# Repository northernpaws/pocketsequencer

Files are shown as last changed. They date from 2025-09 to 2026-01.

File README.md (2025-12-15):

# Pocket Sequencer

> This sequencer is being revised in revision 2 as a target for my embedded Rust audio processing framework, Rythm. Revision 2 will be a carrier board for one of the Rythm modules, and use the Rythm engine for the audio and sequencing.
>
> [https://github.com/northernpaws/rythm](https://github.com/northernpaws/rythm)

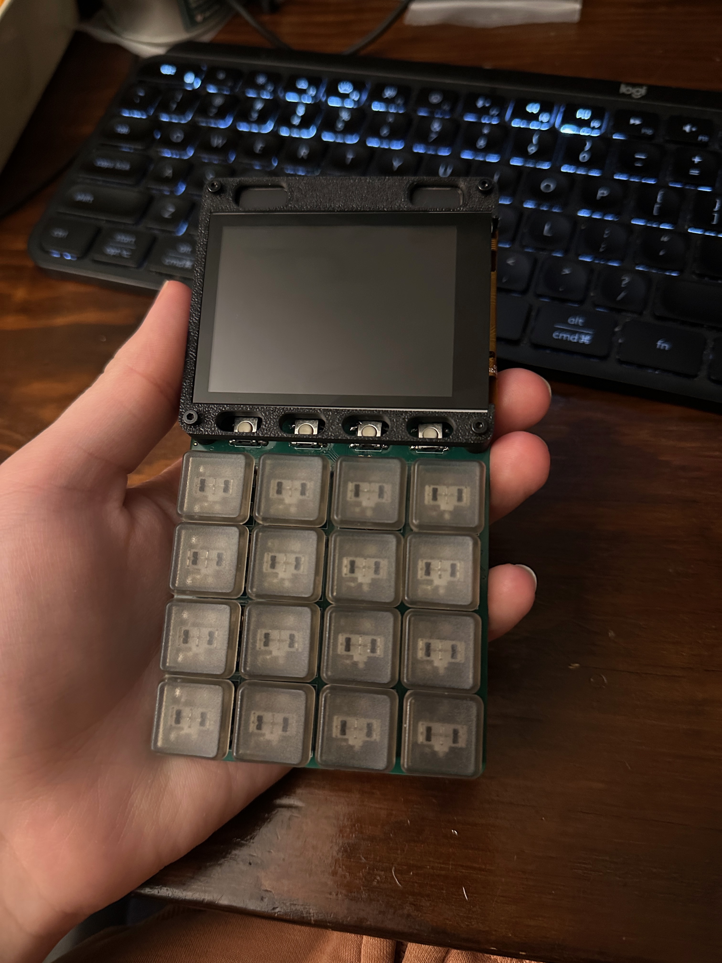
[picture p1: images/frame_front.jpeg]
Photo of front of board
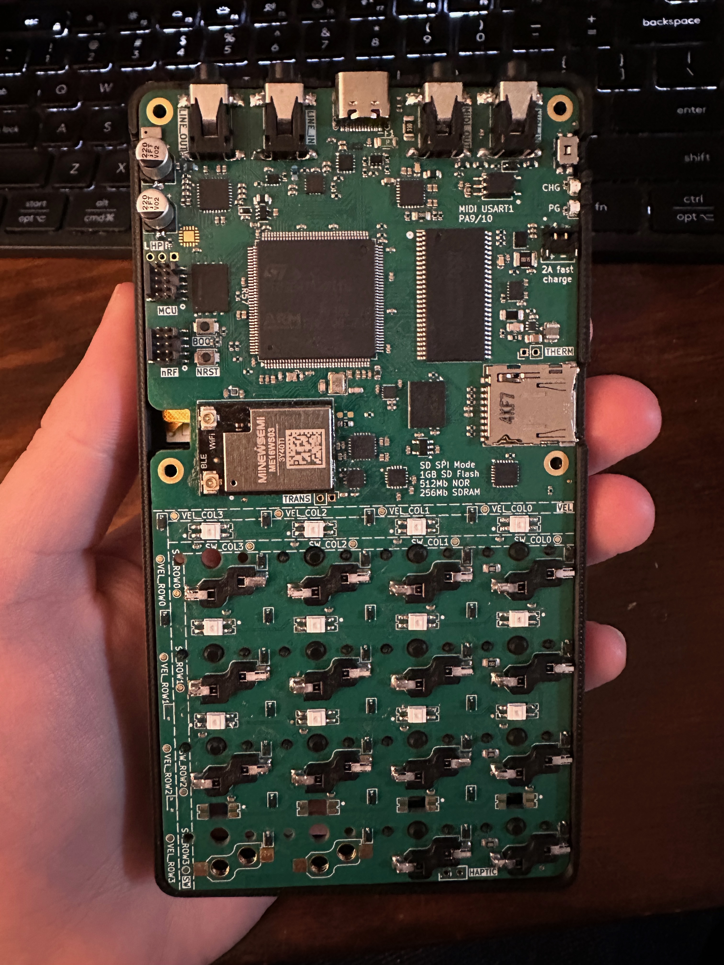
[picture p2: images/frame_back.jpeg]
Photo of back of board
|  |  |
|:---:|:---:|

[Board Schematic](https://kicanvas.org/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)

[Board v0.1 Errata](hardware/boards/v0.1/README.md)

This repository contains my project for an STM32H7-based sequencer, synthesizer, and sampler, all in a small phone-sized pocketable form factor. 

  * 480 MHz Arm® Cortex®-M7 32-bit Processor (`STM32H743ZIT6`)
    * Floating-point unit
    * DSP instructions
    * High-speed memory controller
    * Quad SPI interface for flash
    * High-speed USB host and device mode
    * Several SAI audio blocks
  * 2.8" 240x320 TFT IPS Display (`ER-TFT028A2-4`)
  * 24 bit Audio Codec (`NAU88C22YG`)
    * DAC: 94dB SNR
    * ADC: 90dB SNR
    * 1W 8Ω BTL speaker driver
    * 40mW 16Ω headphone driver
  * Optional Bluetooth and Wifi (`nRF5430`)
    * Wirelessly connect Bluethooth headphones and speakers
    * Supports various high-fedality audio protocols
    * BLE MIDI
    * Wifi sample management and transfer
  * Interal stereo 8W speakers speaker
  * Internal MEMs microphone
  * SDRAM for sample pool and audio processing
    * Part allocated to in-memory sample pool for project
    * Part allocated to audio effects processing
    * Variable sizes in similar footprint available, up to 512Mbit:
        * 16bit * 48000Hz = 768,000b/s = 0.768Mb/s
        * 128Mb / 0.768Mb/s = 166.66 seconds of mono audio (`IS42S16800J-7TL`)
        * 256Mb / 0.768Mb/s = 333.33 seconds of mono audio (`IS42S16160J-7TLI`)
        * 512Mb / 0.768Mb/s = 666.66 seconds of mono audio (`IS42S16320F-7TLI`)
  * Micro SD Card
    * Saving and loading projects
      * Transfer and back up projects to a computer
    * Saving and loading samples
      * Load samples from a computer
      * Save samples recorded on the device
  * 3.3v NOR Flash (`MT25QUxxxxxx1xW7` 256M/128M/64M)
    * Stores device settings
    * Small storage space for projects and samples without SD card
    * Provides storage for cross-SD card samples
  * USB-C
    * USB-PD fast charging
    * Possible future audio interface mode
    * USB MIDI in and out
  * MIDI in/out via TRS minijack type A
  * 16 Multi-Purpose primary keys
    * Hot-swappable Kalih V1 Choc keyswitches
    * Addressable RGB LEDs for state indicators
  * Accelerometer and Gyroscope (`LSM6DS3`)
    * Can be used as sequencer parameters
    * Can be recorded for automation inputs

Photo of front of board

## Step Sequencer

The step sequencer on the device is modeled after popular semantics used by hardware sequencers, such as the Elektron Digitone and Digitakt, OP-1, OP-Z, Pocket Operators, Woovebox, etc.

> The hard requirements of the step sequencer and audio engine are not defined yet because they are under active development.

  * As many projects as the SD card or internal memory can store
    * 128 Patterns (TBD)
      * 8-16 Audio or MIDI tracks per pattern (TBD)
    * 8-24 Songs (arrangements of patterns) (TBD)
  * 8-16 voice polyphony (TBD)
    * 2-3 LFO per voice (TBD)

## Audio Samples

The primary audio engine runs in 32-bit and supports stereo audio.

### Sampling

The sampling engine runs 16bit 44.1Khz and saves and loads samples in single-channel mono.

Samples recoded from the internal or external mic are sampled at 24 bits into the device's SDRAM to provide a decent noise floor, and then filtered and downsampled to 16 bits for saving after they've been edited by the user.

The 16bit @ 44.1Khz sampling parameters provdes a good balance between audio quality, and reasonable utilization of the SDRAM without needing extremely large and expensive SDRAM chips:

```
16bit * 48000Hz = 768,000b/s = 0.768Mb/s
128Mb / 0.768Mb/s = 166.66 seconds of mono audio
256Mb / 0.768Mb/s = 333.33 seconds of mono audio
512Mb / 0.768Mb/s = 666.66 seconds of mono audio
```

> Note that some of the space calculated above (actual amount will be configurable) is allocated to the audio effects processing chain, i.e. for reverb and delay. 

## References

### Debugging

 - HardFault: Under XPERIPHERALS in Cortex-debug check the `CFSR_UFSR_BFSR_MMFSR` register to see the fault code and reference: https://community.st.com/t5/stm32-mcus/how-to-debug-a-hardfault-on-an-arm-cortex-m-stm32/ta-p/672235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

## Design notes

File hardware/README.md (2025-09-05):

# Hardware

## Components

  * [480 MHz Arm® Cortex®-M7 32-bit Processor (`STM32H743ZIT6`)](https://www.st.com/en/microcontrollers-microprocessors/stm32h743zi.html)
    * Floating-point unit
    * DSP instructions
    * High-speed memory controller
    * Quad SPI interface for flash
    * High-speed USB host and device mode
    * Several SAI audio blocks
  * [24 bit Audio Codec (`NAU88C22YG`)](https://www.nuvoton.com/products/smart-home-audio/audio-converters/audio-codec-series/nau88c22yg/)
    * DAC: 94dB SNR and -84dB THD (“A” weighted)
    * ADC: 90dB SNR and -80dB THD (“A” weighted)
    * Integrated BTL speaker driver: 1W into 8Ω
    * Integrated head-phone driver: 40mW into 16Ω
  * [Optional Bluetooth Audio & MIDI (`nRF5340`)](https://www.nordicsemi.com/Products/nRF5340)
    * Wirelessly connect Bluethooth headphones and speakers
    * Connect devices for BLE MIDI inputs and outputs
    * uFL connector for case-mounted antenna
  * [Optional Wi-Fi (`ESP32-S2-MINI-2U`)](https://www.espressif.com/sites/default/files/documentation/esp32-s2-mini-2_esp32-s2-mini-2u_datasheet_en.pdf)
    * Wi-Fi sample management and transfer
    * uFL connector for case-mounted antenna

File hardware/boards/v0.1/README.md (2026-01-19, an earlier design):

# v0.1

## Components

  * [480 MHz Arm® Cortex®-M7 32-bit Processor (`STM32H743ZIT6`)](https://www.st.com/en/microcontrollers-microprocessors/stm32h743zi.html)
    * Floating-point unit
    * DSP instructions
    * High-speed memory controller
    * Quad SPI interface for flash
    * High-speed USB host and device mode
    * Several SAI audio blocks
  * [24 bit Audio Codec (`NAU88C22YG`)](https://www.nuvoton.com/products/smart-home-audio/audio-converters/audio-codec-series/nau88c22yg/)
    * DAC: 94dB SNR and -84dB THD (“A” weighted)
    * ADC: 90dB SNR and -80dB THD (“A” weighted)
    * Integrated BTL speaker driver: 1W into 8Ω
    * Integrated head-phone driver: 40mW into 16Ω
  * [Optional Bluetooth Audio & MIDI (`nRF5340`)](https://www.nordicsemi.com/Products/nRF5340)
    * Wirelessly connect Bluethooth headphones and speakers
    * Connect devices for BLE MIDI inputs and outputs
  * [Optional Wi-Fi (`nRF7002`)](https://www.nordicsemi.com/Products/nRF7002)
    * Wi-Fi sample management and transfer

## Observations

### Routing

  - In next revision, use larger STM32 package. Ran out of pins on the left side due to the FMC and SDRAM, and had to route several GPIO across the entire board, including some interrupt traces in the power layer. Ran out of ADC pins for the velocity pads and had to add an $8 IO expander.

## Errata

 - QUADSPI CS should be NSS capable pin for automatic hardware peripheral control. Use PG6 and swap USB_INT to PD6.
 - Micro SD Card detect pins weren't connected, card detection needs to happen in software.
 - SPI1 hardward CS pins should be PA4, PA15, or PG10. Currently using PA4 (SD CARD) and PC13 (internal flash).
 - Unused key matrix pins should be connected to VCC via a pull-up.
 - Keypad diodes should be pointing to the columns, not the rows.
   - "Once the TCA8418 has had the keypad array configured, it will enter idle mode when no keys are being pressed.
      All columns configured as part of the keypad array will be driven low and all rows configured as part of the
      keypad array will be set to inputs, with pull-up resistors enabled. During idle mode, the internal oscillator is turned
      off so that power consumption is low as the device awaits a key press."
  - Missing pull-up on keypad interrupt. Compensated for in software.
  - Fuel gauge interrupt missing pull-up resistor.
  - Mounting holes are not grounded, oops..
  - PG and cahrger lights are on regardless of power state
  - Should have a 3v3 power light
  - Somehow connect vref from the BMP port to the power button on confirmation
  - Should add flow control pins to RF UART "H:4 HCI transport protocol (requires HW flow control from the UART)".
  - Touch screen connector is inverted...
  - LED footprint needs longer pads with some overhang
  - Dispaly connector needs slightly longer pads
  - Display mode pins are backwards...
  - LEDs need a power enable switch tied to the main regulator, they never shut off.
  - Either attach power enable pin to the BMP's Vref so the BMP can assert it high, or have a flashing/development jumper on the back.
  - TCA8418 doesn't provide a way to query the matrix state after an active reset. The TAC8418 only emits keypress events when they happen, so we can't check on power on if a key is held from before a reset.
  - The filtering capacitors on the audio line in and out are too small, they should be at least 47uF. In their current 1uF value, they cut out large parts of the low-end.
  - The filter capacitors on the audio line in and out where acidentally changed from film to ceramics during BOM selections, causing extra signal noise.

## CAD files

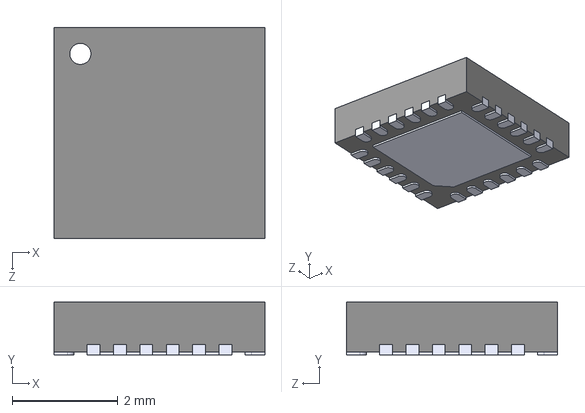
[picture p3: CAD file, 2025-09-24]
hardware/3dmodels/TAS2505IRGER.step
4.00 x 1.00 x 4.00 mm

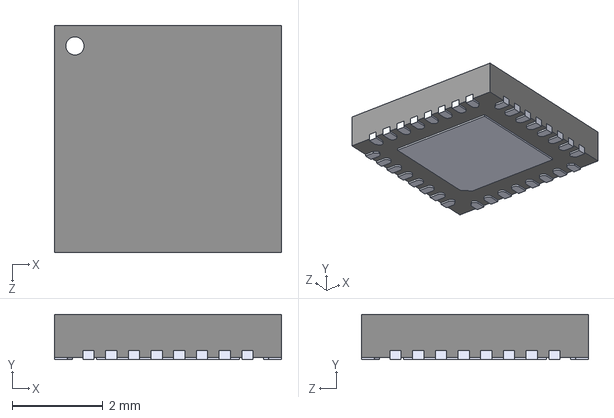
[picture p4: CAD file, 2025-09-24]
hardware/3dmodels/TLV320DAC3100IRHBT.step
5.00 x 1.00 x 5.00 mm

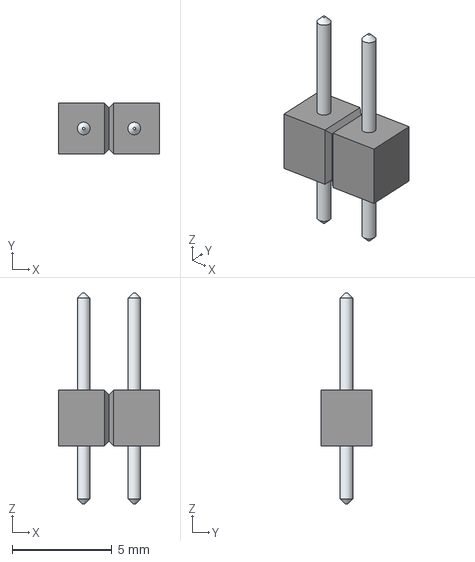
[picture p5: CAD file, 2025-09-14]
hardware/3dmodels/825-22-002-10-001101.stp
5.08 x 2.54 x 10.6 mm
LeadsArray

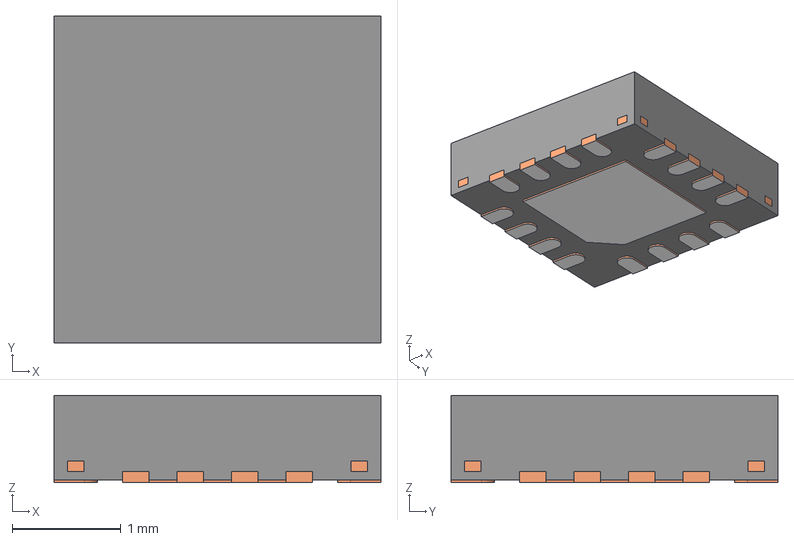
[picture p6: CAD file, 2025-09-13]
hardware/3dmodels/ADS7128IRTER.stp
3.00 x 3.00 x 0.8 mm
BODY-QFN
FRAME-RTE0016C
PIN1-ID

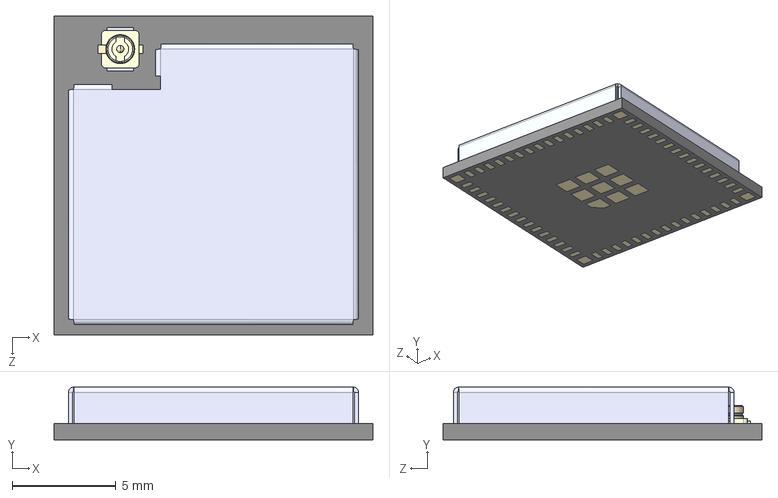
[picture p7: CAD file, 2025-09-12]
hardware/3dmodels/ESP32-S3-MINI-1U-N8.STEP
15.4 x 2.55 x 15.4 mm
ESP32-S3-MINI-1U-N8_ESP32-C3-MINI-1-N4
antenna jack

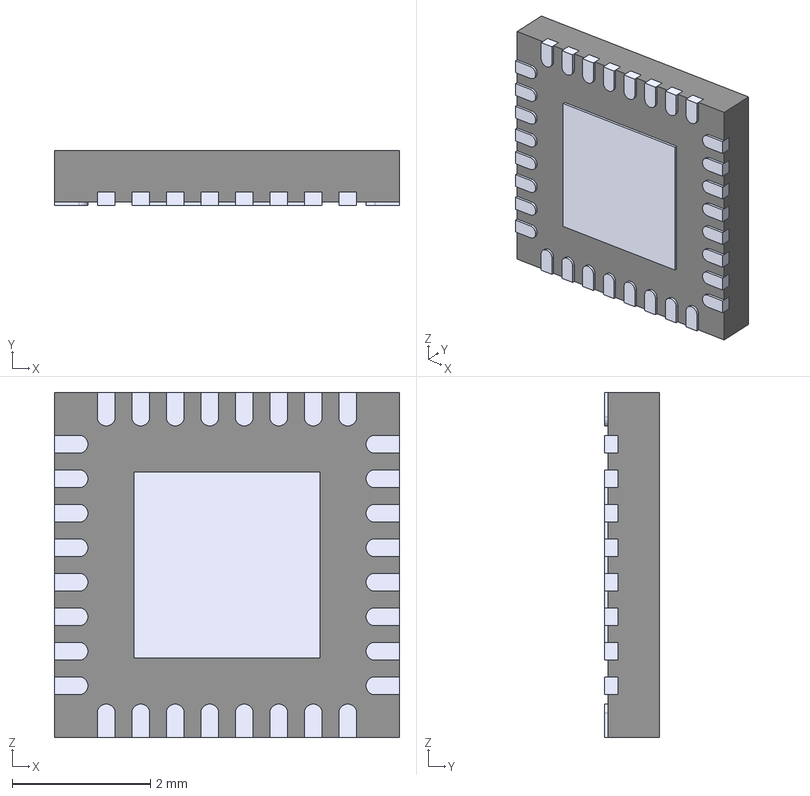
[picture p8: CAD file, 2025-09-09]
hardware/3dmodels/NAU88C22YG.STEP
5.00 x 0.8 x 5.00 mm
Body_Solid1
Body001_Solid1
Array_Solid1 x 8
Array001_Solid2 x 7
Body002_Solid1
Array002_Solid1 x 8
Array003_Solid2 x 7
Body003_Solid1
Body004_Solid1

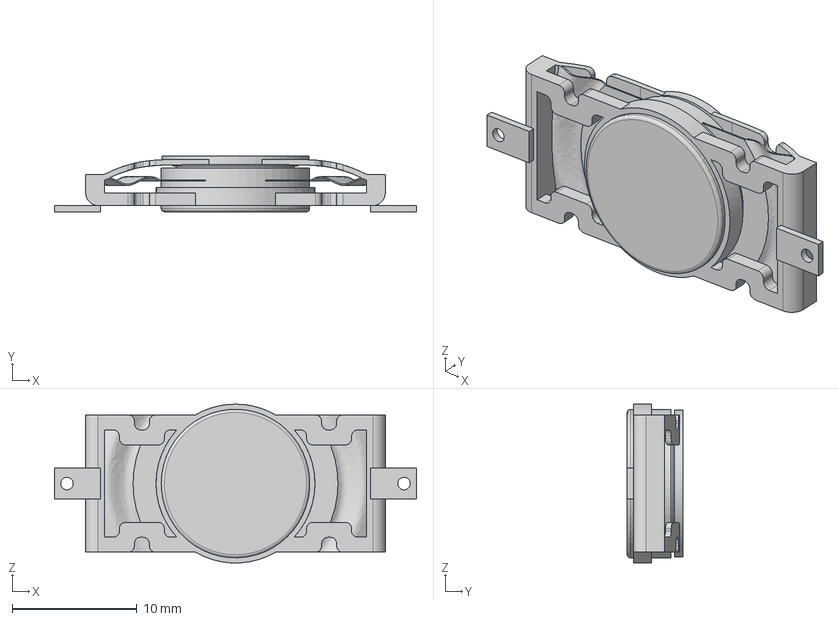
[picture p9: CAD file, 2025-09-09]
hardware/3dmodels/DAEX-9-4SM.step
29.0 x 4.45 x 12.7 mm

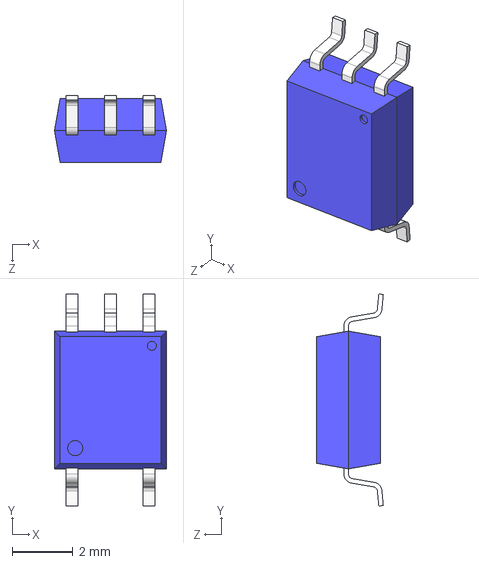
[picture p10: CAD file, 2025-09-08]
hardware/3dmodels/5pin SO6.step
3.70 x 7.00 x 2.20 mm

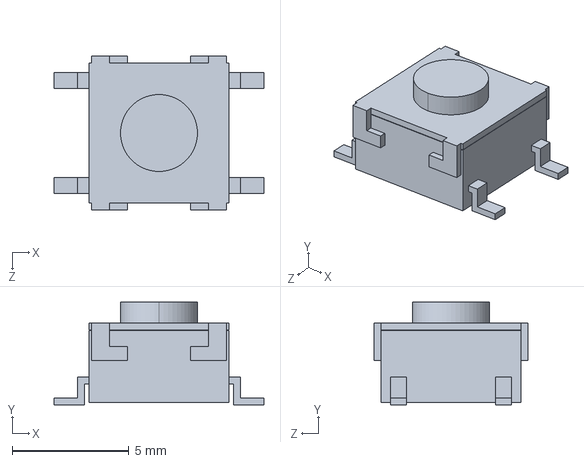
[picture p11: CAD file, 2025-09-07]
hardware/3dmodels/B3S_100[].step
9.00 x 4.40 x 6.60 mm

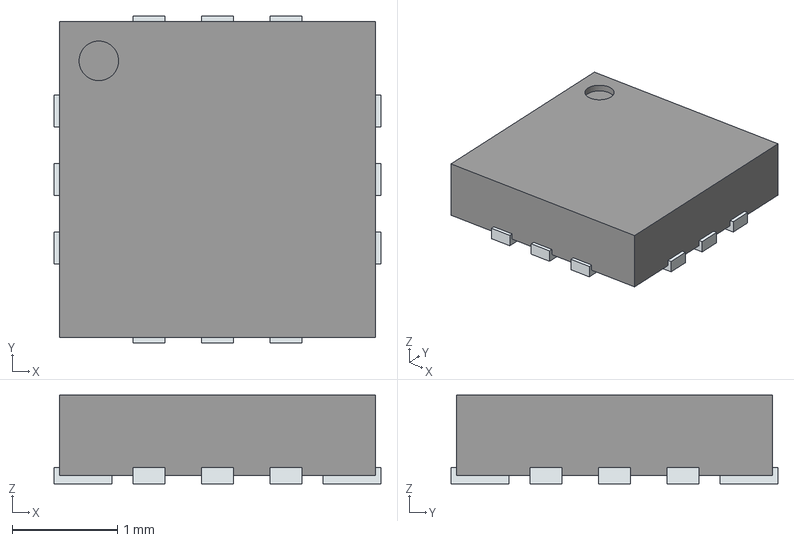
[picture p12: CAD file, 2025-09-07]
hardware/3dmodels/DA7280-00FVC.stp
3.10 x 3.10 x 0.84 mm
PinsArrayLR
PinsArrayTB

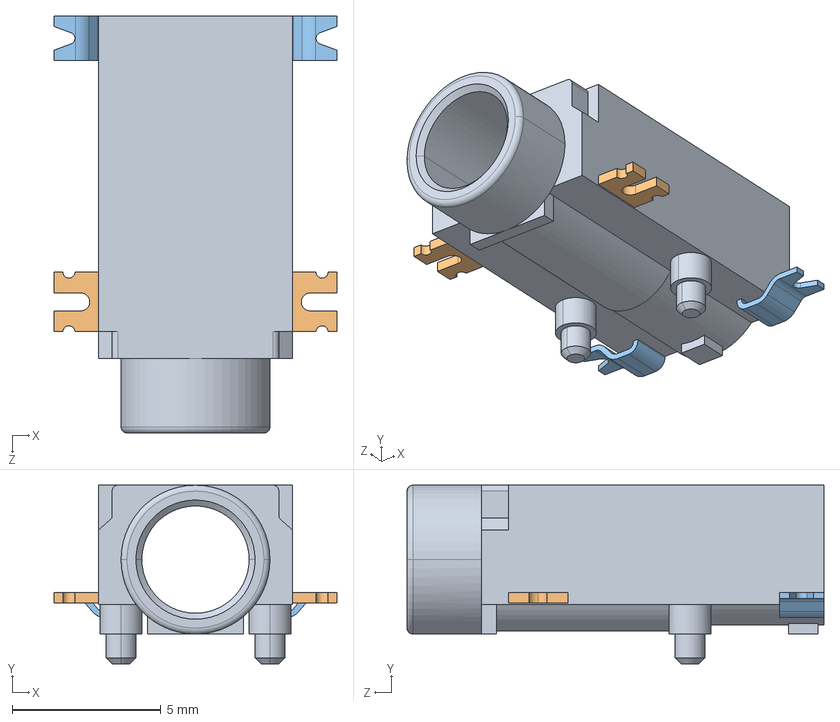
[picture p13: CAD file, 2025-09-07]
hardware/3dmodels/lumberg_1503_02.stp
9.50 x 6.00 x 14.0 mm

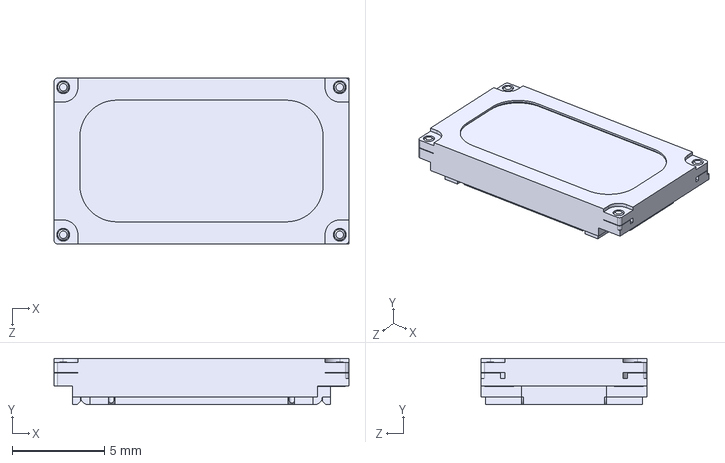
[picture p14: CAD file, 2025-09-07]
hardware/3dmodels/Same_Sky_CMS-160925-078SP.step
16.0 x 2.50 x 9.00 mm

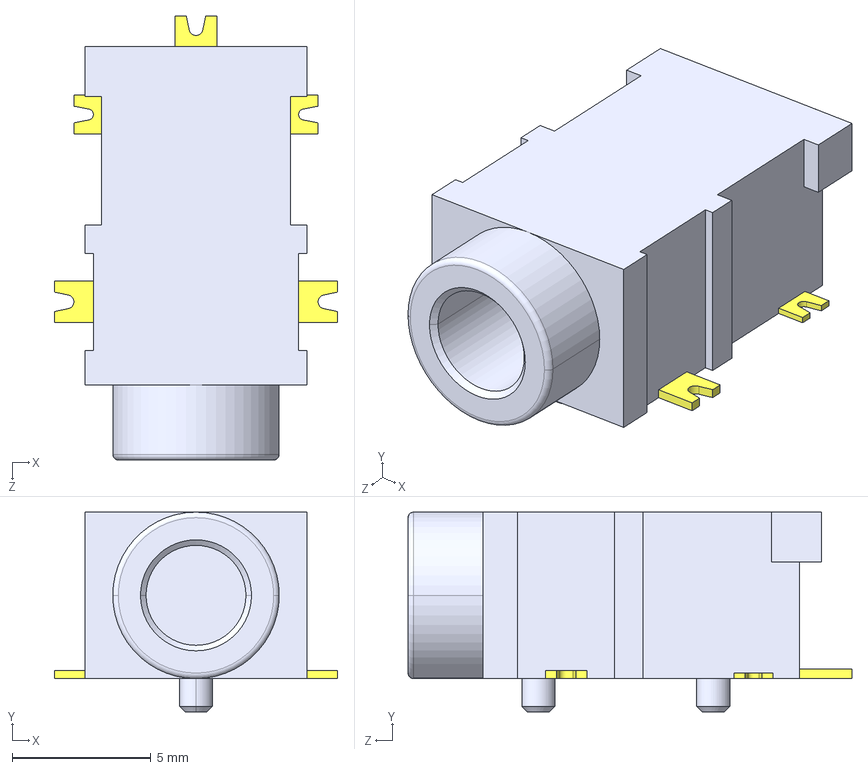
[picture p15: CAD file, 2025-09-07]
hardware/3dmodels/lumberg_1503_03.stp
10.2 x 7.20 x 16.0 mm

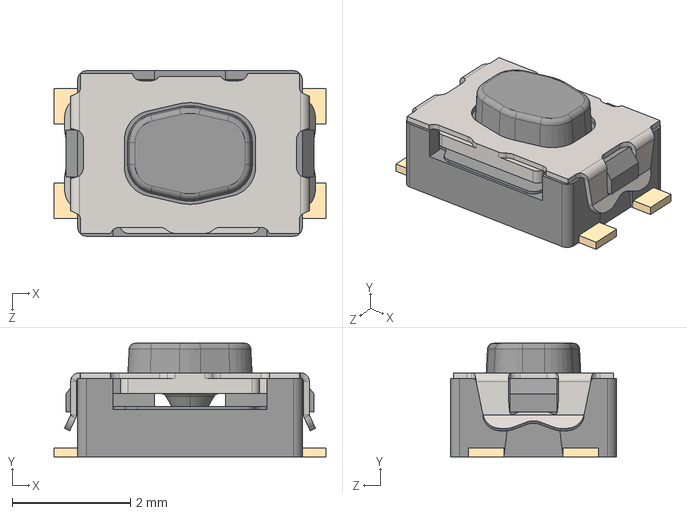
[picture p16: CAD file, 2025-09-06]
hardware/3dmodels/KMR221NG_LFS.stp
4.60 x 1.92 x 2.80 mm

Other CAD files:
hardware/3dmodels/WM8904CGEFL_RV.step
hardware/3dmodels/LED_SK6812MINI-E.step
hardware/3dmodels/NORA-B100.step
hardware/3dmodels/2082940020.stp
hardware/3dmodels/436331045822.stp
hardware/3dmodels/5034800540.stp
hardware/3dmodels/532610271.STEP
hardware/3dmodels/541325097.stp
hardware/3dmodels/687106182122+(rev1).stp
hardware/3dmodels/AS01808AO-SC18-WP-R.step
hardware/3dmodels/BQ27531YZFR-G1.step
hardware/3dmodels/CON10_2X5_DUK_FTSH_SAI.step
hardware/3dmodels/CON14_2X7_DUK_FTSH_SAI.step
hardware/3dmodels/DM3AT-SF-PEJM5.stp
hardware/3dmodels/DM3BT-DSF-PEJS.stp
hardware/3dmodels/ECS-.327-12.5-1210-TR.step
hardware/3dmodels/ER-TFT028-4.2.stp
hardware/3dmodels/ER-TFT028-4.2.x_t
hardware/3dmodels/FSA2466UMX.step
hardware/3dmodels/FTSH-105-01-F-D-K.step
hardware/3dmodels/FTSH-105-01-F-D-K.stp
hardware/3dmodels/FTSH-105-01-F-DV-K.stp
hardware/3dmodels/FTSH-107-01-F-DV-K.stp
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

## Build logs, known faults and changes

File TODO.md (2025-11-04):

# rev 2

 - QUADSPI CS should be NSS capable pin for automatic hardware peripheral control. Use PG6 and swap USB_INT to maybe PD6? 
 - Run LCD display DMA in circular mode, and use half-interrupt and end interrupt to queue double-buffer frame drawing in sync with DMA transfer speeds. 
   - "On the STM32, you can allocate one big array, and use the two halves as double buffer. There is a half-transfer interrupt (when enabled) which tells you that the first half is filled and ready for processing, and the second half is being modified. Then you'll get a transfer complete interrupt when the second half is ready and (in circular mode) it goes on updating the first half again. On higher-end controllers (STM32F4, STM32F7), there are actually two memory addresses for each DMA channel, the buffers halves do not need to be contiguous, and you can even change the address of the inactive buffer on the fly."

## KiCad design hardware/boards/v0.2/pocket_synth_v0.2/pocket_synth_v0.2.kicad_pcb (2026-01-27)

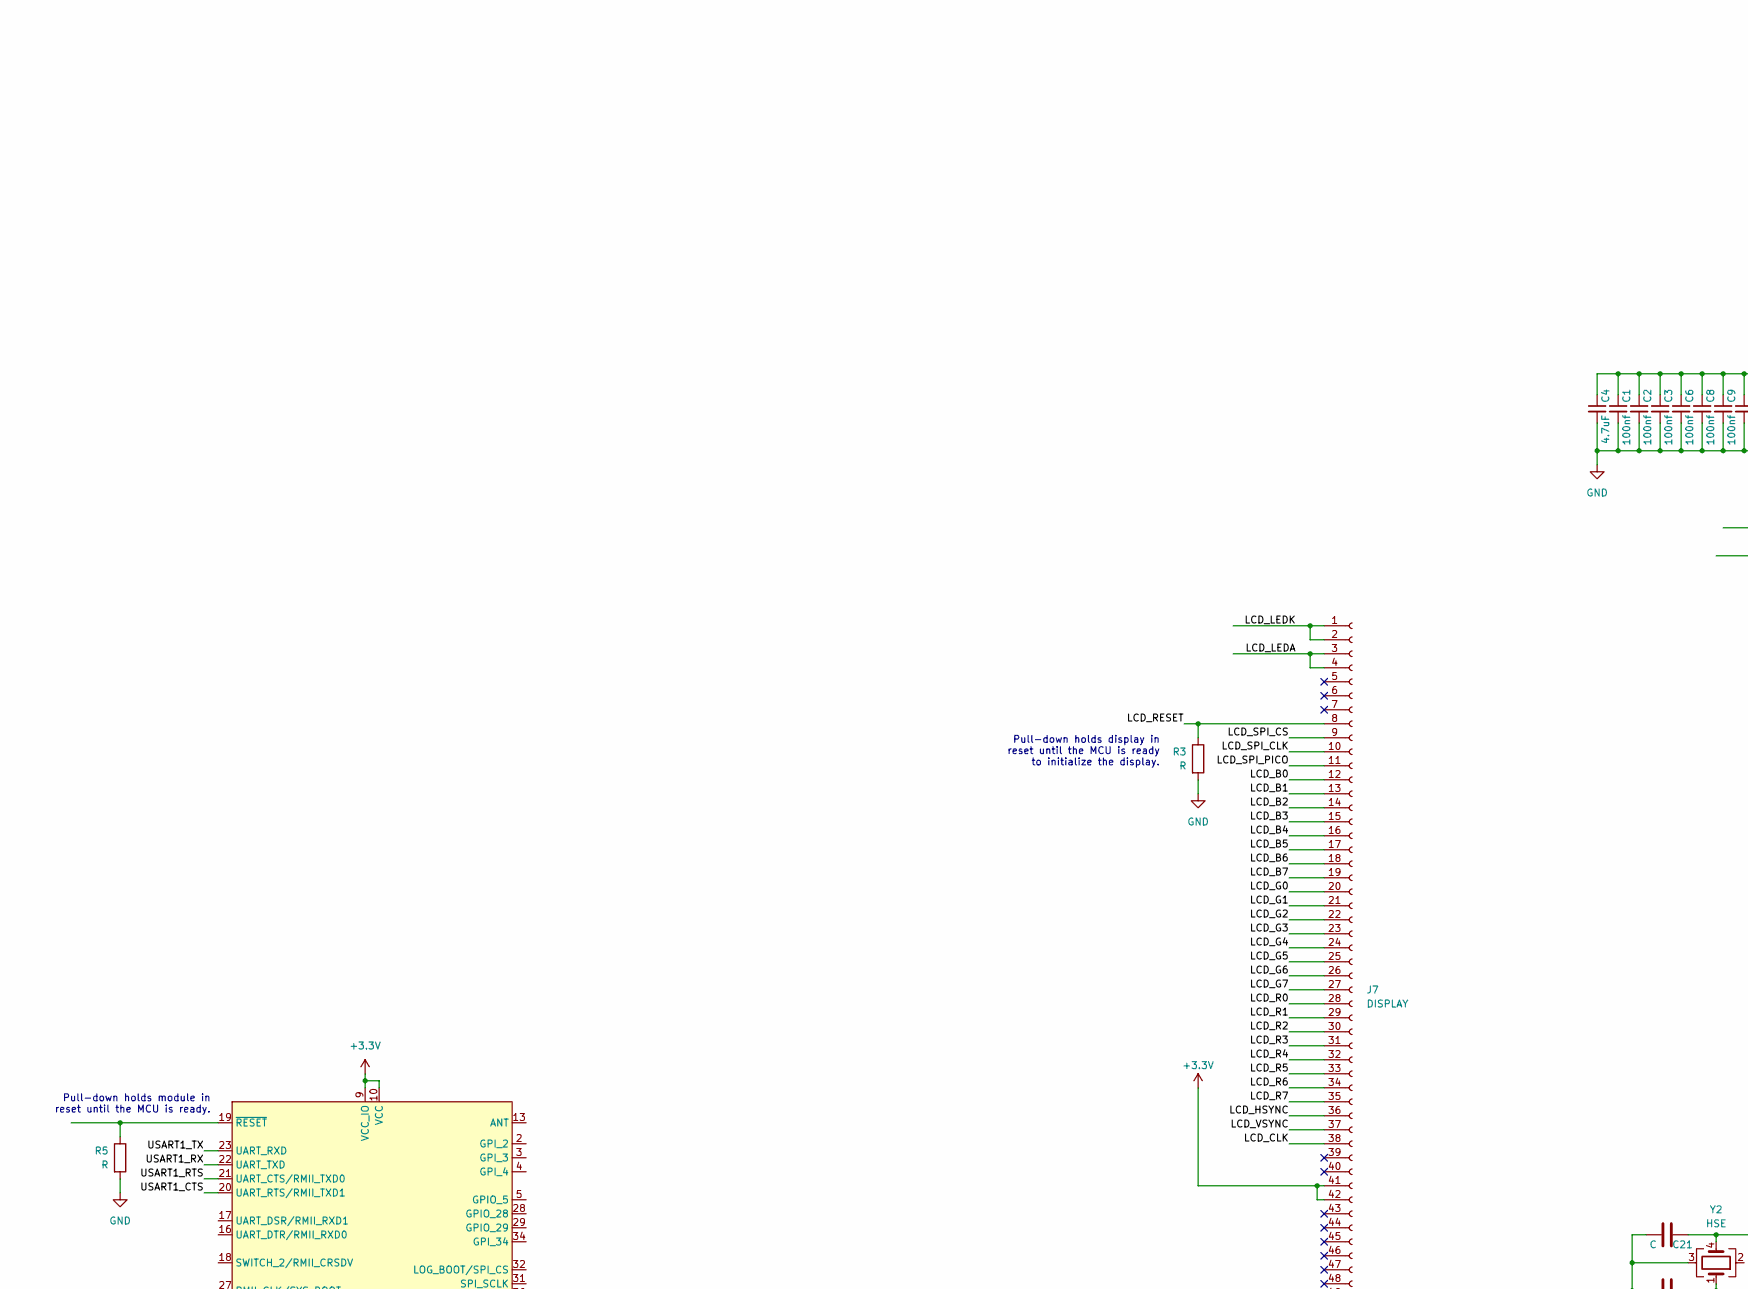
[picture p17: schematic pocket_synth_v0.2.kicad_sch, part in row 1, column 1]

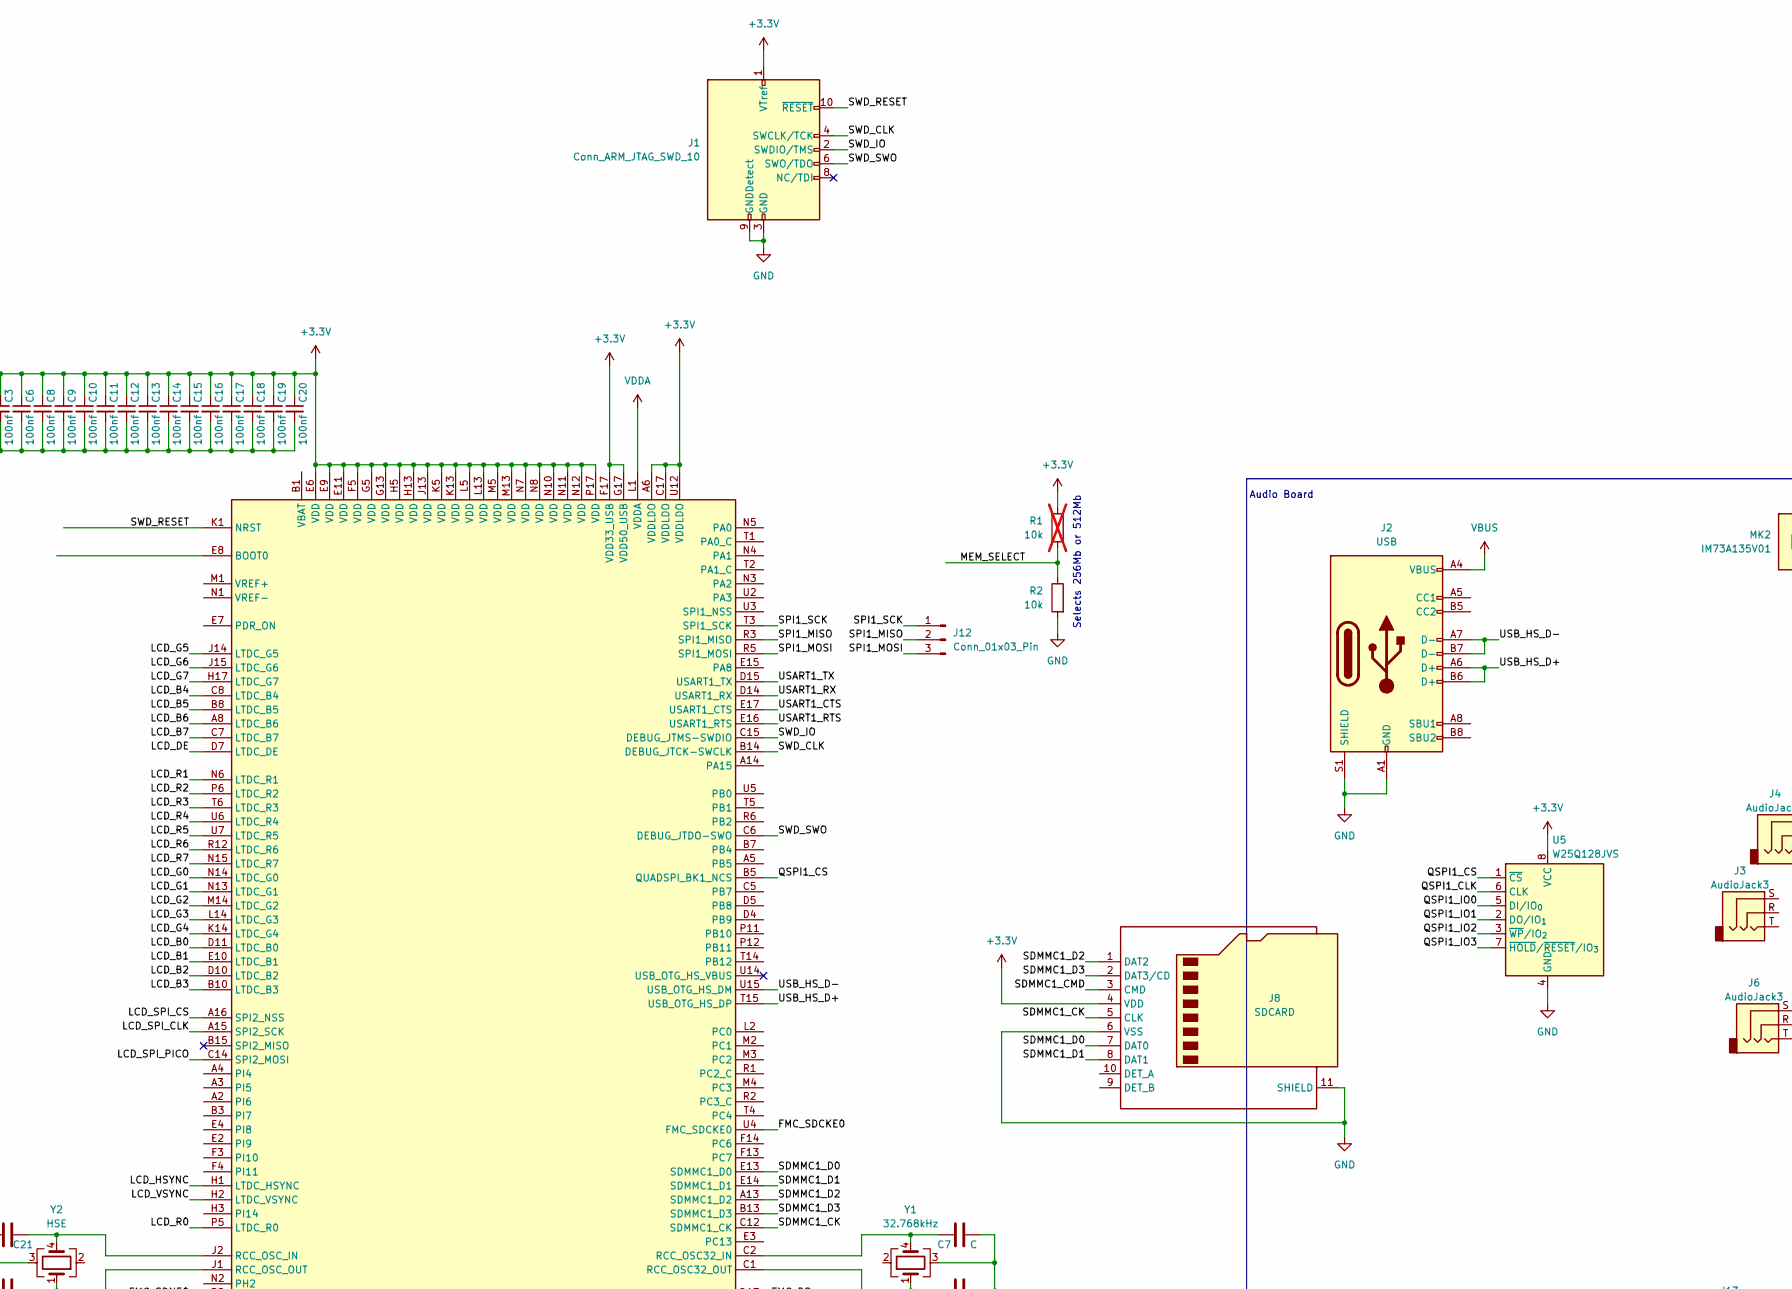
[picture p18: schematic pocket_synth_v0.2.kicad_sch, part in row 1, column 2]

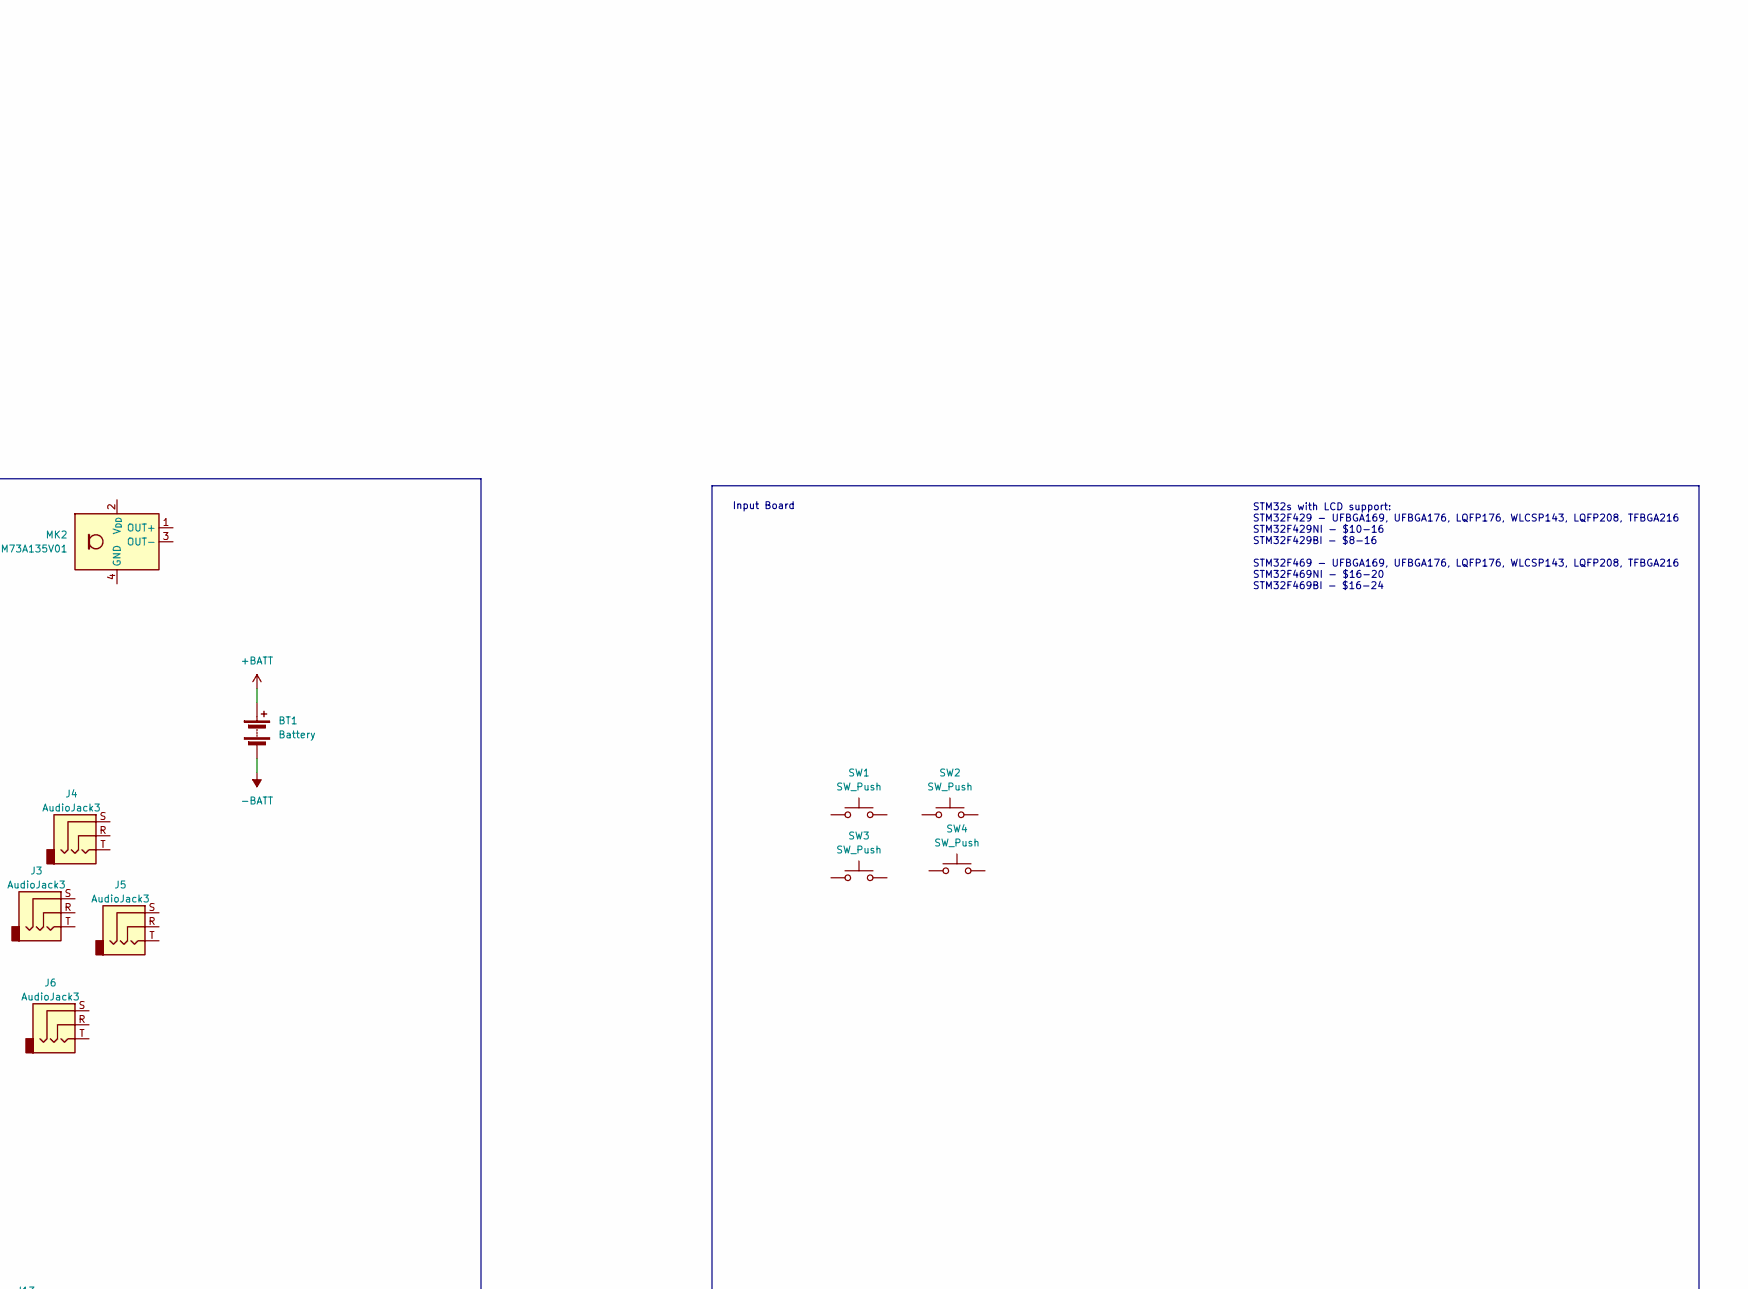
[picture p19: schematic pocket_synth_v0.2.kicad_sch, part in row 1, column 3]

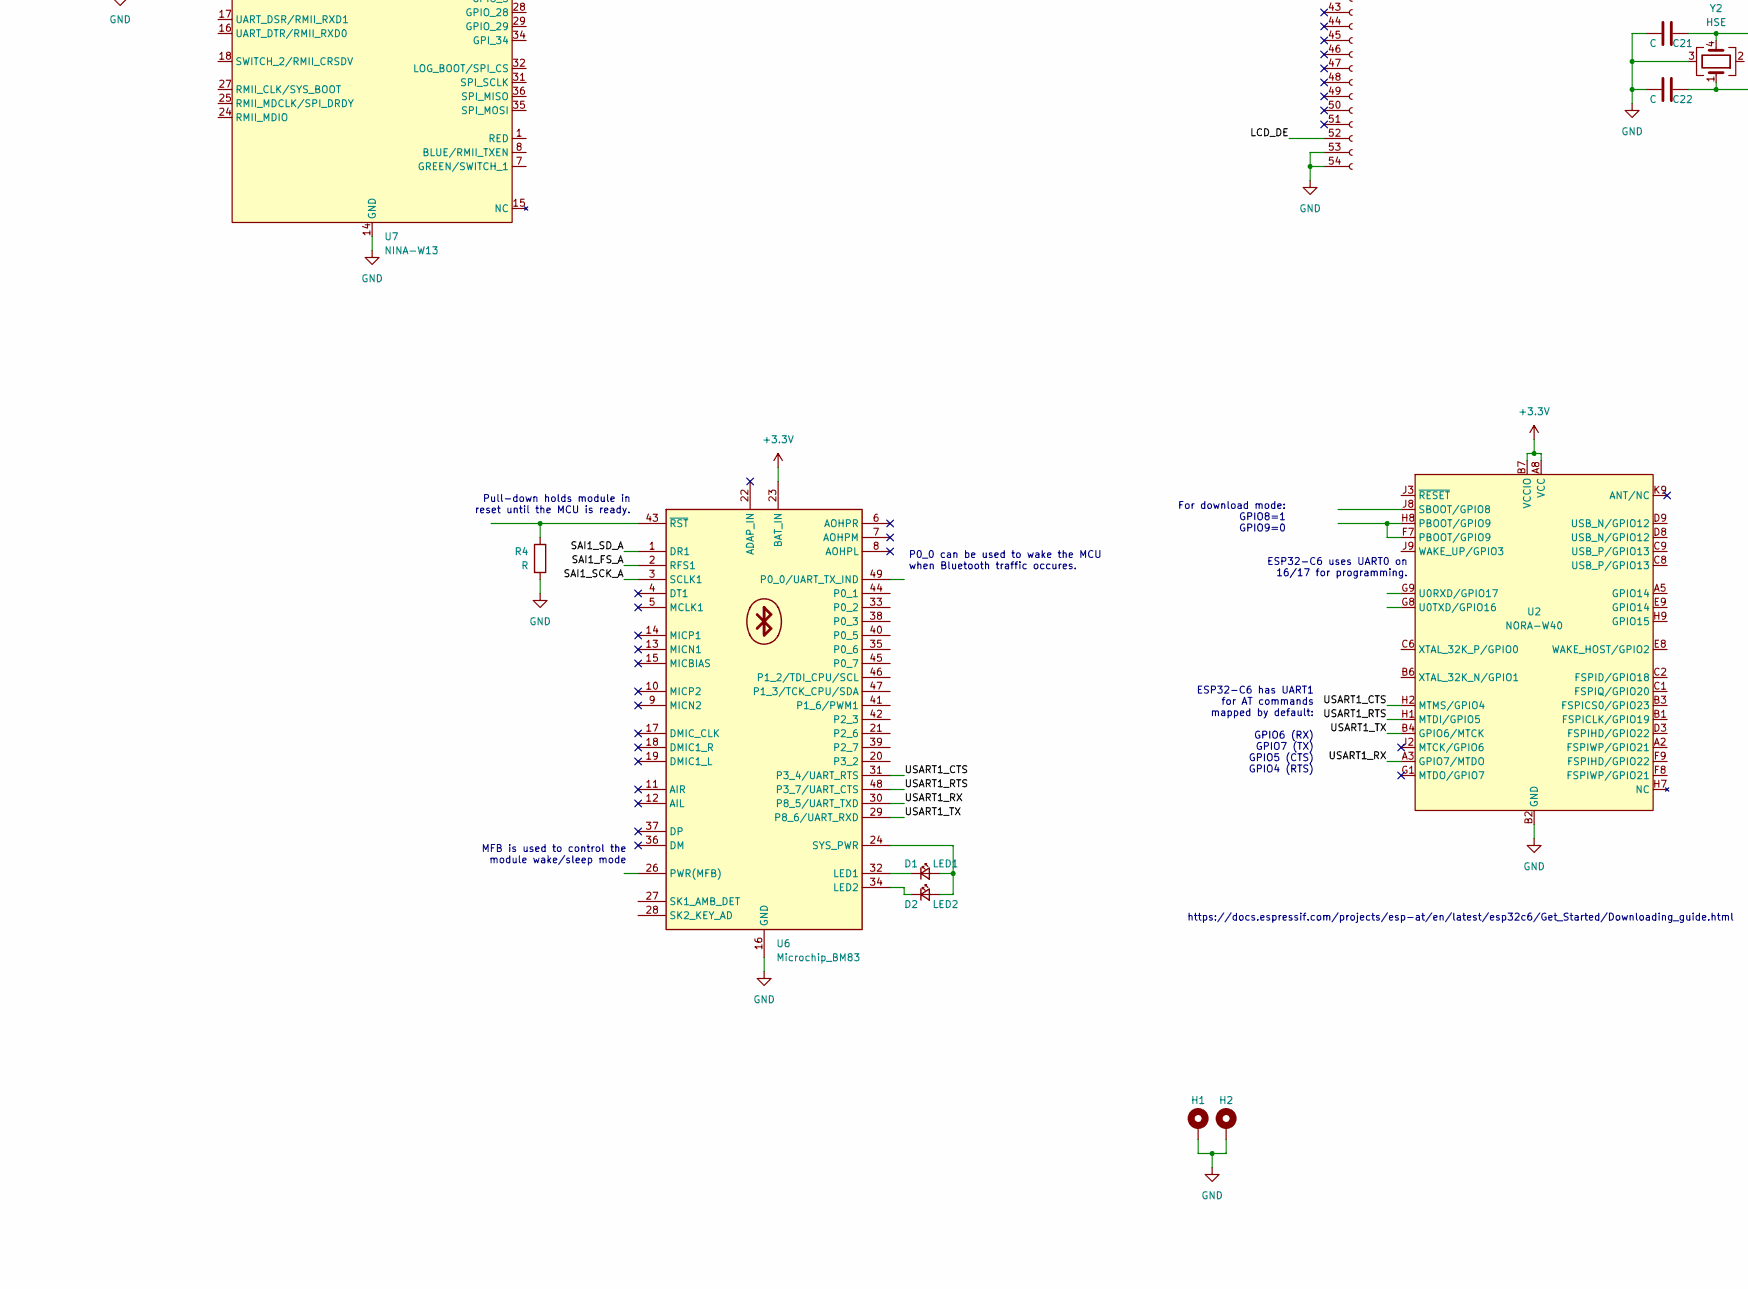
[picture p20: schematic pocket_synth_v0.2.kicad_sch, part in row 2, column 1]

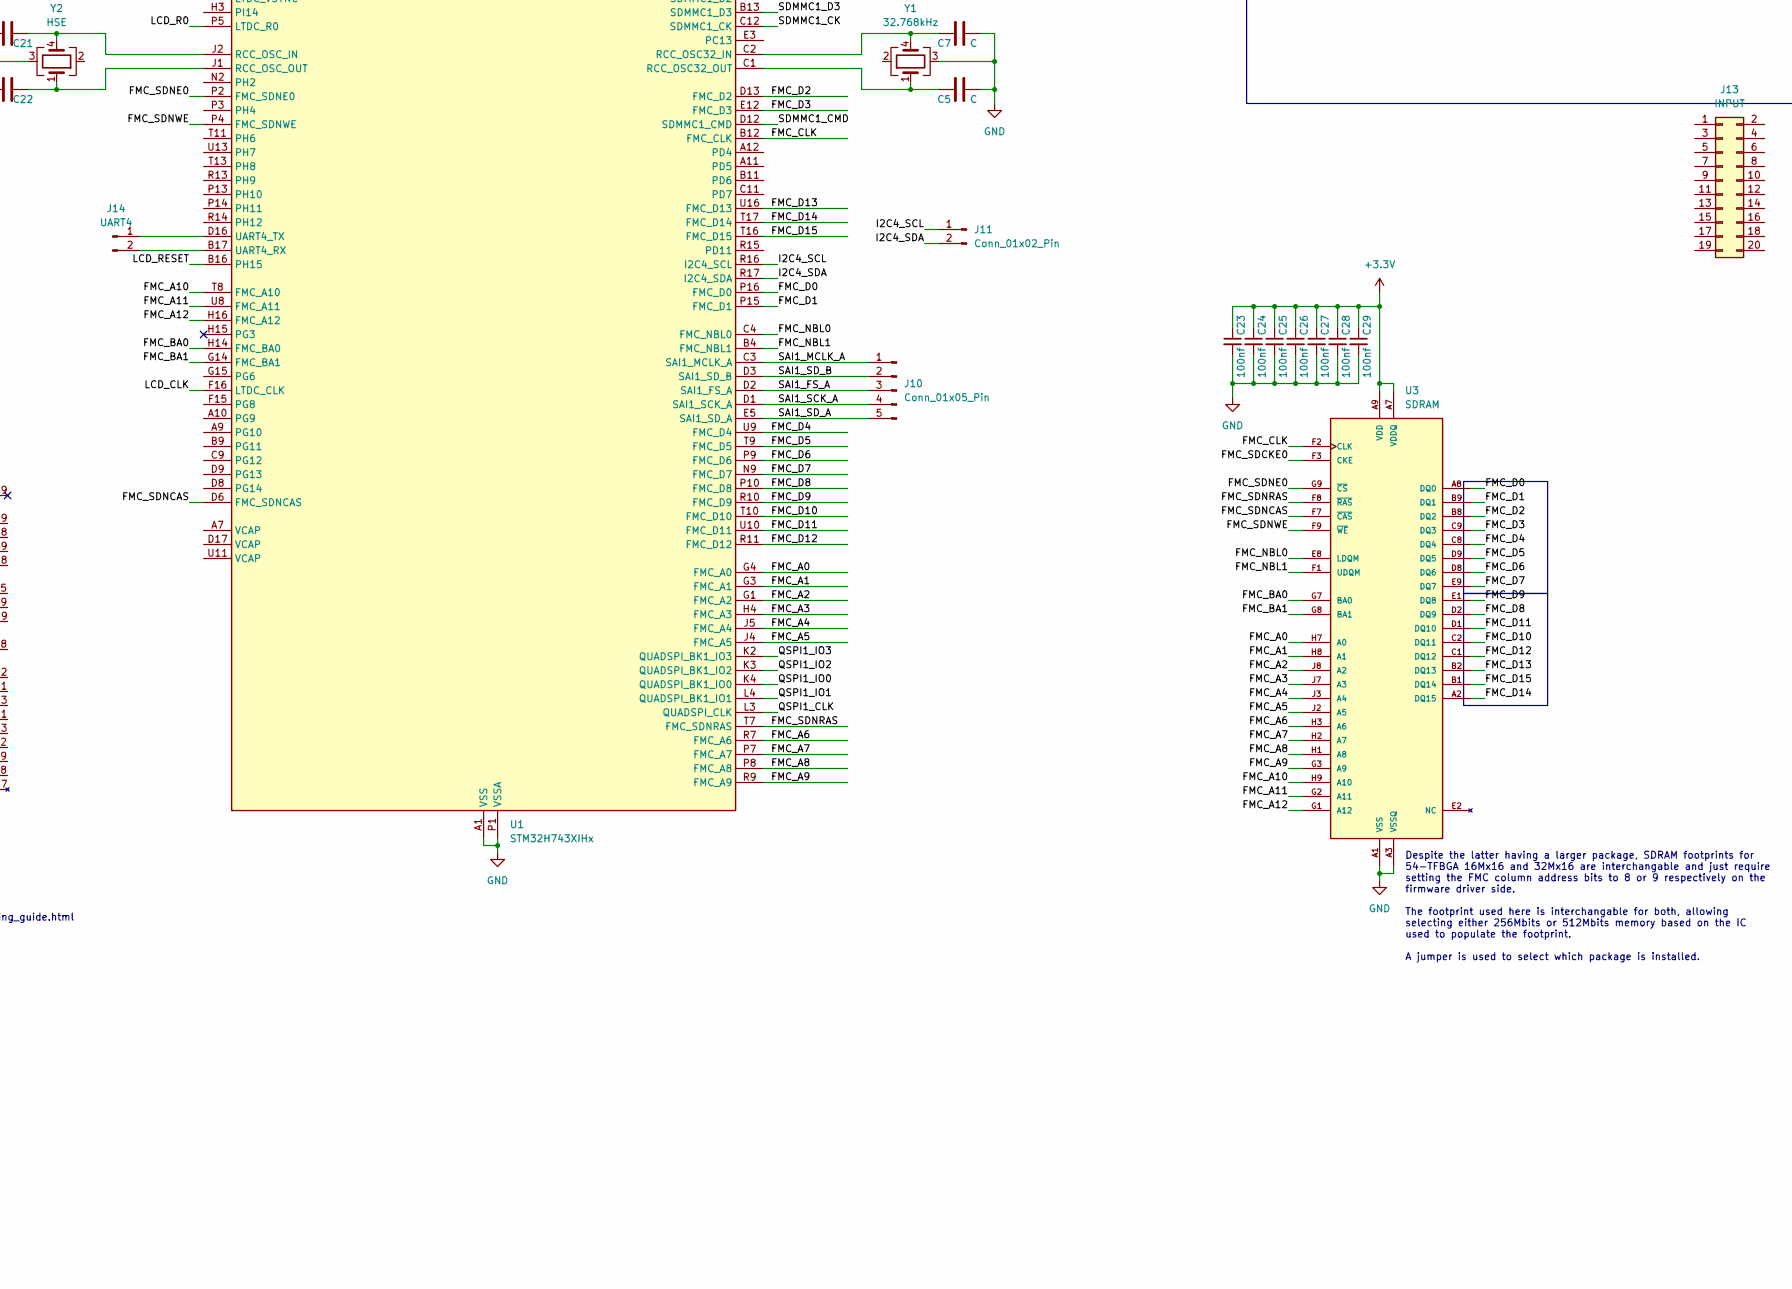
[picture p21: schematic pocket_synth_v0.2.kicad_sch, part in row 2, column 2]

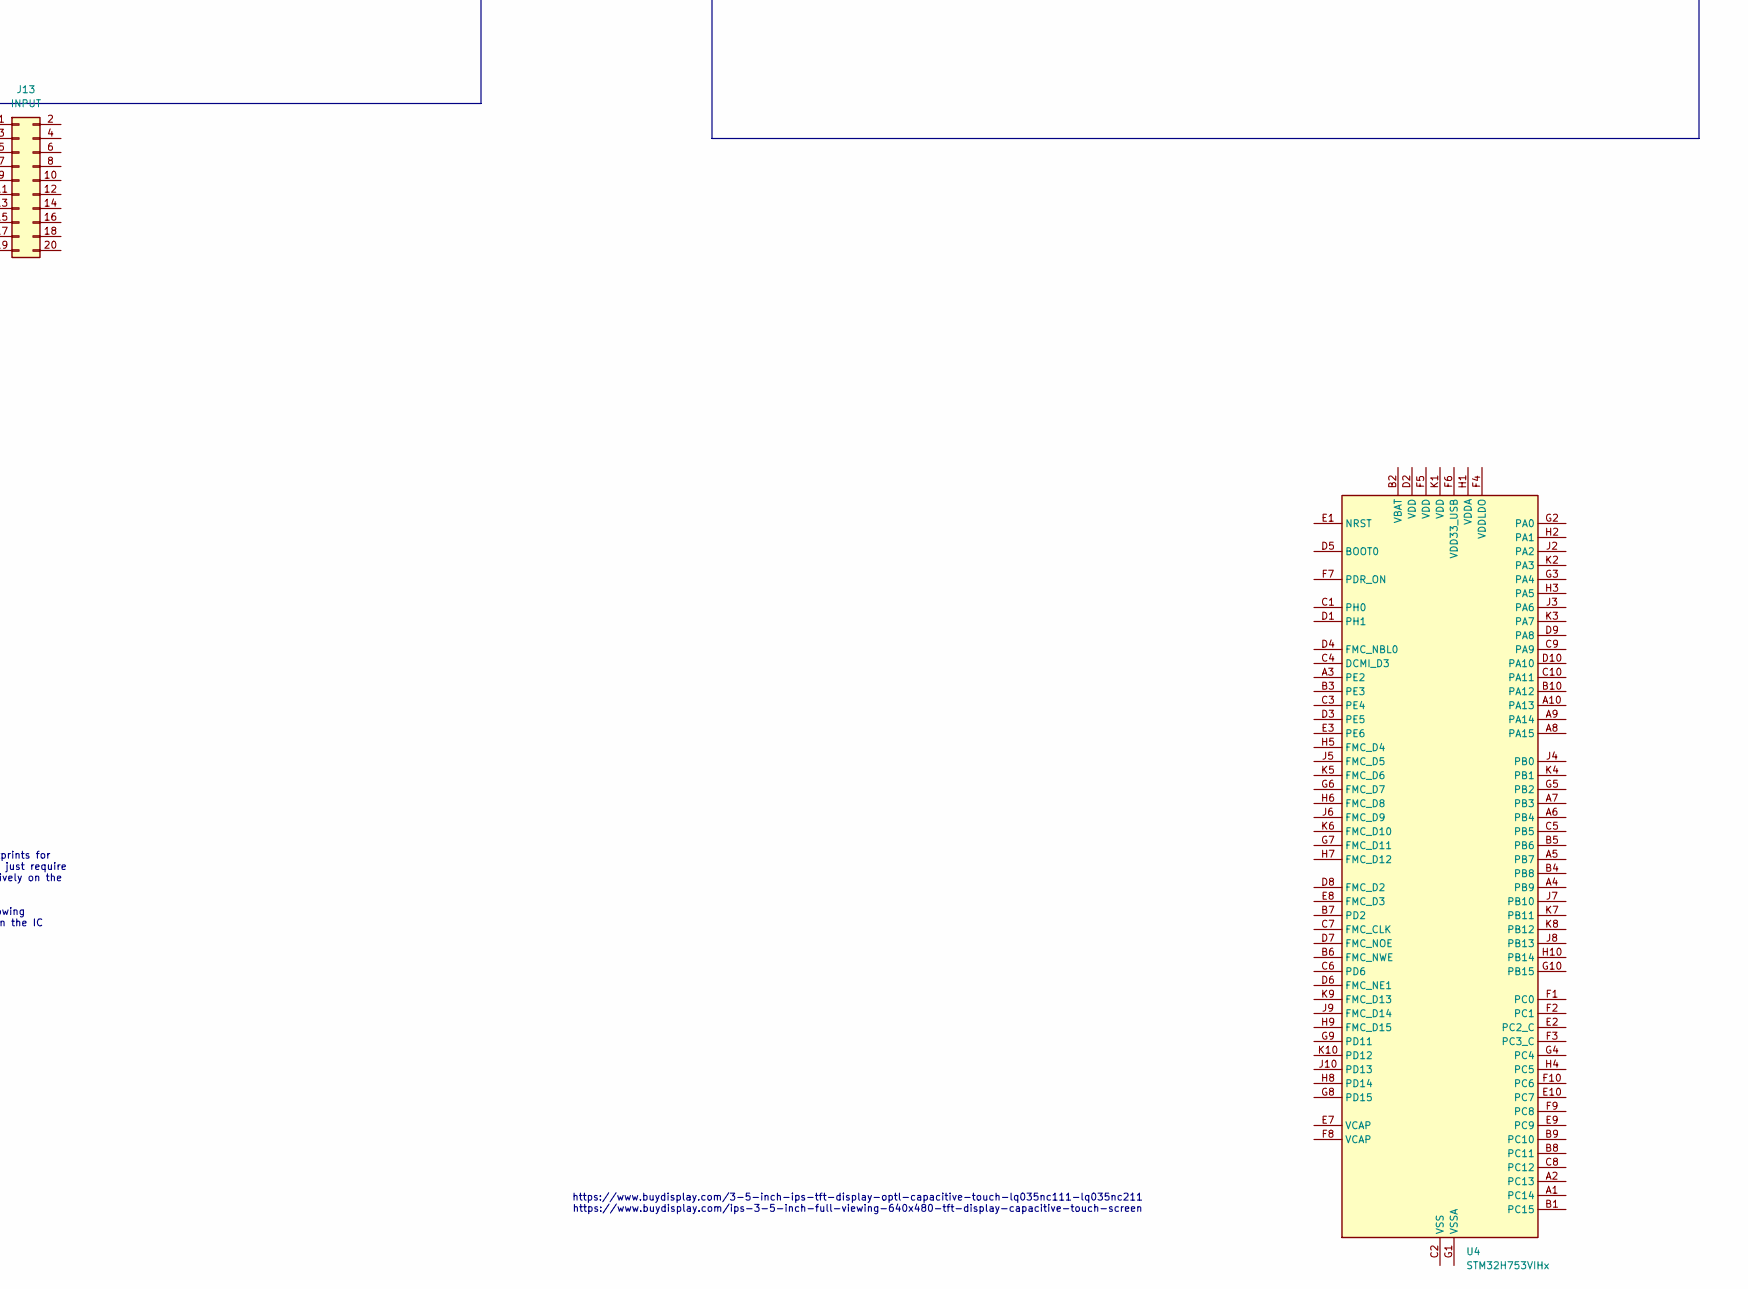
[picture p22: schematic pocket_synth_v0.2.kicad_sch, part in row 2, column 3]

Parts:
BT1: Battery; JST_PH_S2B-PH-K_1x02_P2.00mm_Horizontal
C1, C2, C3, C6, C8, C9, C10, C11, C12, C13, C14, C15, C16, C17, C18, C19, C20, C23, C24, C25, C26, C27, C28, C29: 100nf; C_0402_1005Metric
C4: 4.7uF; C_0402_1005Metric
C5, C7, C21, C22: C; C_0805_2012Metric
D1: LED1
D2: LED2
H1, H2: MountingHole_Pad; MountingHole_2.2mm_M2_Pad
J1: Conn_ARM_JTAG_SWD_10; PinHeader_2x05_P1.27mm_Vertical_SMD
J2: USB; USB_C_Receptacle_HCTL_HC-TYPE-C-16P-01A
J3, J4, J5, J6: AudioJack3; Jack_3.5mm_CUI_SJ-3523-SMT_Horizontal
J7: DISPLAY; Amphenol_F32Q-1A7x1-11054_1x54-1MP_P0.5mm_Horizontal
J8: SDCARD; microSD_HC_Hirose_DM3AT-SF-PEJM5
J10: Conn_01x05_Pin; PinHeader_1x05_P1.00mm_Vertical
J11: Conn_01x02_Pin; PinHeader_1x02_P1.00mm_Vertical
J12: Conn_01x03_Pin; PinHeader_1x03_P1.00mm_Vertical
J13: INPUT; Hirose_DF40C-20DS-0.4V_2x10_P0.4mm
J14: UART4; PinHeader_1x02_P1.00mm_Vertical
MK2: IM73A135V01; Infineon_PG-LLGA-5-2
R1: 10k; R_0603_1608Metric_Pad0.98x0.95mm_HandSolder; not fitted
R2: 10k; R_0603_1608Metric_Pad0.98x0.95mm_HandSolder
R3, R4, R5: R; R_0603_1608Metric
SW1, SW2, SW3, SW4: SW_Push; SW_SPST_SKQG_WithoutStem
U1: STM32H743XIHx; TFBGA-265_14x14mm_Layout17x17_P0.8mm
U2: NORA-W40
U3: SDRAM; IC54_IS42S16320F-7BLI_ISI; PARTREV Rev. 1.2; DigiKey_Part_Number 1450-AS4C32M16SB-7BIN-ND
U4: STM32H753VIHx; TFBGA-100_8x8mm_Layout10x10_P0.8mm
U5: W25Q128JVS; SOIC-8_5.3x5.3mm_P1.27mm
U6: Microchip_BM83
U7: NINA-W13; ublox-NINA-W13
Y1: 32.768kHz; Crystal_SMD_Abracon_ABM10-4Pin_2.5x2.0mm
Y2: HSE; Crystal_SMD_Abracon_ABM10-4Pin_2.5x2.0mm

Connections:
+3.3V: C1.1, C2.1, C3.1, C4.1, C6.1, C8.1, C9.1, C10.1, C11.1, C12.1, C13.1, C14.1, C15.1, C16.1, C17.1, C18.1, C19.1, C20.1, C23.1, C24.1, C25.1, C26.1, C27.1, C28.1, C29.1, J1.1 (VTref), J7.41, J7.42, J8.4 (VDD), R1.1, U1.A6 (VDDLDO), U1.C17 (VDDLDO), U1.E6 (VDD), U1.E9 (VDD), U1.E11 (VDD), U1.F5 (VDD), U1.F17 (VDD33_USB), U1.G5 (VDD), U1.G13 (VDD), U1.G17 (VDD50_USB), U1.H5 (VDD), U1.H13 (VDD), U1.J13 (VDD), U1.K5 (VDD), U1.K13 (VDD), U1.L5 (VDD), U1.L13 (VDD), U1.M5 (VDD), U1.M13 (VDD), U1.N7 (VDD), U1.N8 (VDD), U1.N10 (VDD), U1.N11 (VDD), U1.N12 (VDD), U1.P17 (VDD), U1.U12 (VDDLDO), U2.A7 (VCCIO), U2.A8 (VCC), U2.B7 (VCCIO), U3.A7 (VDDQ), U3.A9 (VDD), U3.B3 (VDDQ), U3.C7 (VDDQ), U3.D3 (VDDQ), U3.E7 (VDD), U3.J9 (VDD), U5.8 (VCC), U6.23 (BAT_IN), U7.9 (VCC_IO), U7.10 (VCC)
+BATT: BT1.1 (+)
-BATT: BT1.2 (-)
/FMC_A0: U1.G4 (FMC_A0), U3.H7 (A0)
/FMC_A1: U1.G3 (FMC_A1), U3.H8 (A1)
/FMC_A2: U1.G1 (FMC_A2), U3.J8 (A2)
/FMC_A3: U1.H4 (FMC_A3), U3.J7 (A3)
/FMC_A4: U1.J5 (FMC_A4), U3.J3 (A4)
/FMC_A5: U1.J4 (FMC_A5), U3.J2 (A5)
/FMC_A6: U1.R7 (FMC_A6), U3.H3 (A6)
/FMC_A7: U1.P7 (FMC_A7), U3.H2 (A7)
/FMC_A8: U1.P8 (FMC_A8), U3.H1 (A8)
/FMC_A9: U1.R9 (FMC_A9), U3.G3 (A9)
/FMC_A10: U1.T8 (FMC_A10), U3.H9 (A10)
/FMC_A11: U1.U8 (FMC_A11), U3.G2 (A11)
/FMC_A12: U1.H16 (FMC_A12), U3.G1 (A12)
/FMC_BA0: U1.H14 (FMC_BA0), U3.G7 (BA0)
/FMC_BA1: U1.G14 (FMC_BA1), U3.G8 (BA1)
/FMC_CLK: U1.B12 (FMC_CLK), U3.F2 (CLK)
/FMC_D0: U1.P16 (FMC_D0), U3.A8 (DQ0)
/FMC_D1: U1.P15 (FMC_D1), U3.B9 (DQ1)
/FMC_D2: U1.D13 (FMC_D2), U3.B8 (DQ2)
/FMC_D3: U1.E12 (FMC_D3), U3.C9 (DQ3)
/FMC_D4: U1.U9 (FMC_D4), U3.C8 (DQ4)
/FMC_D5: U1.T9 (FMC_D5), U3.D9 (DQ5)
/FMC_D6: U1.P9 (FMC_D6), U3.D8 (DQ6)
/FMC_D7: U1.N9 (FMC_D7), U3.E9 (DQ7)
/FMC_D8: U1.P10 (FMC_D8), U3.D2 (DQ9)
/FMC_D9: U1.R10 (FMC_D9), U3.E1 (DQ8)
/FMC_D10: U1.T10 (FMC_D10), U3.C2 (DQ11)
/FMC_D11: U1.U10 (FMC_D11), U3.D1 (DQ10)
/FMC_D12: U1.R11 (FMC_D12), U3.C1 (DQ12)
/FMC_D13: U1.U16 (FMC_D13), U3.B2 (DQ13)
/FMC_D14: U1.T17 (FMC_D14), U3.A2 (DQ15)
/FMC_D15: U1.T16 (FMC_D15), U3.B1 (DQ14)
/FMC_NBL0: U1.C4 (FMC_NBL0), U3.E8 (LDQM)
/FMC_NBL1: U1.B4 (FMC_NBL1), U3.F1 (UDQM)
/FMC_SDCKE0: U1.U4 (FMC_SDCKE0), U3.F3 (CKE)
/FMC_SDNCAS: U1.D6 (FMC_SDNCAS), U3.F7 (~CAS)
/FMC_SDNE0: U1.P2 (FMC_SDNE0), U3.G9 (~CS)
/FMC_SDNRAS: U1.T7 (FMC_SDNRAS), U3.F8 (~RAS)
/FMC_SDNWE: U1.P4 (FMC_SDNWE), U3.F9 (~WE)
/I2C4_SCL: J11.1, U1.R16 (I2C4_SCL)
/I2C4_SDA: J11.2, U1.R17 (I2C4_SDA)
/LCD_B0: J7.12, U1.D11 (LTDC_B0)
/LCD_B1: J7.13, U1.E10 (LTDC_B1)
/LCD_B2: J7.14, U1.D10 (LTDC_B2)
/LCD_B3: J7.15, U1.B10 (LTDC_B3)
/LCD_B4: J7.16, U1.C8 (LTDC_B4)
/LCD_B5: J7.17, U1.B8 (LTDC_B5)
/LCD_B6: J7.18, U1.A8 (LTDC_B6)
/LCD_B7: J7.19, U1.C7 (LTDC_B7)
/LCD_CLK: J7.38, U1.F16 (LTDC_CLK)
/LCD_DE: J7.52, U1.D7 (LTDC_DE)
/LCD_G0: J7.20, U1.N14 (LTDC_G0)
/LCD_G1: J7.21, U1.N13 (LTDC_G1)
/LCD_G2: J7.22, U1.M14 (LTDC_G2)
/LCD_G3: J7.23, U1.L14 (LTDC_G3)
/LCD_G4: J7.24, U1.K14 (LTDC_G4)
/LCD_G5: J7.25, U1.J14 (LTDC_G5)
/LCD_G6: J7.26, U1.J15 (LTDC_G6)
/LCD_G7: J7.27, U1.H17 (LTDC_G7)
/LCD_HSYNC: J7.36, U1.H1 (LTDC_HSYNC)
/LCD_LEDA: J7.3, J7.4
/LCD_LEDK: J7.1, J7.2
/LCD_R0: J7.28, U1.P5 (LTDC_R0)
/LCD_R1: J7.29, U1.N6 (LTDC_R1)
/LCD_R2: J7.30, U1.P6 (LTDC_R2)
/LCD_R3: J7.31, U1.T6 (LTDC_R3)
/LCD_R4: J7.32, U1.U6 (LTDC_R4)
/LCD_R5: J7.33, U1.U7 (LTDC_R5)
/LCD_R6: J7.34, U1.R12 (LTDC_R6)
/LCD_R7: J7.35, U1.N15 (LTDC_R7)
/LCD_RESET: J7.8, R3.1, U1.B16 (PH15)
/LCD_SPI_CLK: J7.10, U1.A15 (SPI2_SCK)
/LCD_SPI_CS: J7.9, U1.A16 (SPI2_NSS)
/LCD_SPI_PICO: J7.11, U1.C14 (SPI2_MOSI)
/LCD_VSYNC: J7.37, U1.H2 (LTDC_VSYNC)
/MEM_SELECT: R1.2, R2.1
/QSPI1_CLK: U1.L3 (QUADSPI_CLK), U5.6 (CLK)
/QSPI1_CS: U1.B5 (QUADSPI_BK1_NCS), U5.1 (~CS)
/QSPI1_IO0: U1.K4 (QUADSPI_BK1_IO0), U5.5 (DI/IO_{0})
/QSPI1_IO1: U1.L4 (QUADSPI_BK1_IO1), U5.2 (DO/IO_{1})
/QSPI1_IO2: U1.K3 (QUADSPI_BK1_IO2), U5.3 (~WP/IO_{2})
/QSPI1_IO3: U1.K2 (QUADSPI_BK1_IO3), U5.7 (~HOLD/~RESET/IO_{3})
/SAI1_FS_A: J10.3, U1.D2 (SAI1_FS_A), U6.2 (RFS1)
/SAI1_MCLK_A: J10.1, U1.C3 (SAI1_MCLK_A)
/SAI1_SCK_A: J10.4, U1.D1 (SAI1_SCK_A), U6.3 (SCLK1)
/SAI1_SD_A: J10.5, U1.E5 (SAI1_SD_A), U6.1 (DR1)
/SAI1_SD_B: J10.2, U1.D3 (SAI1_SD_B)
/SDMMC1_CK: J8.5 (CLK), U1.C12 (SDMMC1_CK)
/SDMMC1_CMD: J8.3 (CMD), U1.D12 (SDMMC1_CMD)
/SDMMC1_D0: J8.7 (DAT0), U1.E13 (SDMMC1_D0)
/SDMMC1_D1: J8.8 (DAT1), U1.E14 (SDMMC1_D1)
/SDMMC1_D2: J8.1 (DAT2), U1.A13 (SDMMC1_D2)
/SDMMC1_D3: J8.2 (DAT3/CD), U1.B13 (SDMMC1_D3)
/SPI1_MISO: J12.2, U1.R3 (SPI1_MISO)
/SPI1_MOSI: J12.3, U1.R5 (SPI1_MOSI)
/SPI1_SCK: J12.1, U1.T3 (SPI1_SCK)
/SWD_CLK: J1.4 (SWCLK/TCK), U1.B14 (DEBUG_JTCK-SWCLK)
/SWD_IO: J1.2 (SWDIO/TMS), U1.C15 (DEBUG_JTMS-SWDIO)
/SWD_RESET: J1.10 (~RESET), U1.K1 (NRST)
/SWD_SWO: J1.6 (SWO/TDO), U1.C6 (DEBUG_JTDO-SWO)
/USART1_CTS: U1.E17 (USART1_CTS), U2.H2 (MTMS/GPIO4), U6.31 (P3_4/UART_RTS), U7.20 (UART_RTS/RMII_TXD1)
/USART1_RTS: U1.E16 (USART1_RTS), U2.H1 (MTDI/GPIO5), U6.48 (P3_7/UART_CTS), U7.21 (UART_CTS/RMII_TXD0)
/USART1_RX: U1.D14 (USART1_RX), U2.A3 (GPIO7/MTDO), U6.30 (P8_5/UART_TXD), U7.22 (UART_TXD)
/USART1_TX: U1.D15 (USART1_TX), U2.B4 (GPIO6/MTCK), U6.29 (P8_6/UART_RXD), U7.23 (UART_RXD)
/USB_HS_D+: J2.A6 (D+), J2.B6 (D+), U1.T15 (USB_OTG_HS_DP)
/USB_HS_D-: J2.A7 (D-), J2.B7 (D-), U1.U15 (USB_OTG_HS_DM)
GND: C1.2, C2.2, C3.2, C4.2, C5.2, C6.2, C7.2, C8.2, C9.2, C10.2, C11.2, C12.2, C13.2, C14.2, C15.2, C16.2, C17.2, C18.2, C19.2, C20.2, C21.2, C22.2, C23.2, C24.2, C25.2, C26.2, C27.2, C28.2, C29.2, H1.1, H2.1, J1.3 (GND), J1.5 (GND), J1.9 (GNDDetect), J2.A1 (GND), J2.A12 (GND), J2.B1 (GND), J2.B12 (GND), J2.S1 (SHIELD), J7.53, J7.54, J8.6 (VSS), J8.11 (SHIELD), R2.2, R3.2, R4.2, R5.2, U1.A1 (VSS), U1.A17 (VSS), U1.B2 (VSS), U1.B6 (VSS), U1.C10 (VSS), U1.C13 (VSS), U1.C16 (VSS), U1.F1 (VSS), U1.F2 (VSS), U1.G2 (VSS), U1.G7 (VSS), U1.G8 (VSS), U1.G9 (VSS), U1.G10 (VSS), U1.G11 (VSS), U1.G16 (VSS), U1.H7 (VSS), U1.H8 (VSS), U1.H9 (VSS), U1.H10 (VSS), U1.H11 (VSS), U1.J3 (VSS), U1.J7 (VSS), U1.J8 (VSS), U1.J9 (VSS), U1.J10 (VSS), U1.J11 (VSS), U1.J16 (VSS), U1.J17 (VSS), U1.K7 (VSS), U1.K8 (VSS), U1.K9 (VSS), U1.K10 (VSS), U1.K11 (VSS), U1.K15 (VSS), U1.L7 (VSS), U1.L8 (VSS), U1.L9 (VSS), U1.L10 (VSS), U1.L11 (VSS), U1.L15 (VSS), U1.M15 (VSS), U1.N16 (VSS), U1.P1 (VSSA), U1.R4 (VSS), U1.R8 (VSS), U1.T12 (VSS), U1.U1 (VSS), U1.U17 (VSS), U2.A1 (GND), U2.A9 (GND), U2.B2 (GND), U2.B8 (GND), U2.E4 (GND), U2.E5 (GND), U2.F4 (GND), U2.F5 (GND), U2.K2 (GND), U2.K3 (GND), U2.K5 (GND), U2.K7 (GND), U2.K8 (GND), U2.L1 (GND), U2.L9 (GND), U2.M1 (GND), U2.M2 (GND), U2.M8 (GND), U2.M9 (GND), U3.A1 (VSS), U3.A3 (VSSQ), U3.B7 (VSSQ), U3.C3 (VSSQ), U3.D7 (VSSQ), U3.E3 (VSS), U3.J1 (VSS), U5.4 (GND), U6.16 (GND), U6.50 (GND), U6.56 (GND), U6.57 (GND), U7.6 (GND), U7.12 (GND), U7.14 (GND), U7.26 (GND), U7.30 (GND), U7.37 (GND), U7.38 (GND), U7.39 (GND), U7.40 (GND), U7.41 (GND), U7.42 (GND), U7.43 (GND), U7.44 (GND), U7.45 (GND), U7.46 (GND), U7.47 (GND), U7.48 (GND), Y1.3, Y2.3
unnamed: D1.2 (A), D2.2 (A), U6.24 (SYS_PWR)
unnamed: D1.1 (K), U6.32 (LED1)
unnamed: D2.1 (K), U6.34 (LED2)
unnamed: J14.1, U1.D16 (UART4_TX)
unnamed: J14.2, U1.B17 (UART4_RX)
unnamed: MK2.4 (GND), MK2.5 (GND)
unnamed: C7.1, U1.C2 (RCC_OSC32_IN), Y1.4
unnamed: C5.1, U1.C1 (RCC_OSC32_OUT), Y1.1
unnamed: C21.1, U1.J2 (RCC_OSC_IN), Y2.4
unnamed: C22.1, U1.J1 (RCC_OSC_OUT), Y2.1
unnamed: U2.F7 (PBOOT/GPIO9), U2.H8 (PBOOT/GPIO9)
unnamed: U4.C2 (VSS), U4.E4 (VSS), U4.E5 (VSS), U4.E6 (VSS), U4.J1 (VSS)
unnamed: R4.1, U6.43 (~RST)
unnamed: R5.1, U7.19 (~RESET)
VBUS: J2.A4 (VBUS), J2.A9 (VBUS), J2.B4 (VBUS), J2.B9 (VBUS)
VDDA: U1.L1 (VDDA)

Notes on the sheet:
Audio Board
Pull-down holds module in reset until the MCU is ready.
P0_0 can be used to wake the MCU when Bluetooth traffic occures.
MFB is used to control the module wake/sleep mode
STM32s with LCD support: STM32F429 - UFBGA169, UFBGA176, LQFP176, WLCSP143, LQFP208, TFBGA216 STM32F429NI - $10-16 STM32F429BI - $8-16 STM32F469 - UFBGA169, UFBGA176, LQFP176, WLCSP143, LQFP208, TFBGA216 STM32F469NI - $16-20 STM32F469BI - $16-24
ESP32-C6 has UART1 for AT commands mapped by default: GPIO6 (RX) GPIO7 (TX) GPIO5 (CTS) GPIO4 (RTS)
Despite the latter having a larger package, SDRAM footprints for 54-TFBGA 16Mx16 and 32Mx16 are interchangable and just require setting the FMC column address bits to 8 or 9 respectively on the firmware driver side. The footprint used here is interchangable for both, allowing selecting either 256Mb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
ESP32-C6 uses UART0 on 16/17 for programming.
Pull-down holds display in reset until the MCU is ready to initialize the display.
For download mode: GPIO8=1 GPIO9=0
https://www.buydisplay.com/3-5-inch-ips-tft-display-optl-capacitive-touch-lq035nc111-lq035nc211 https://www.buydisplay.com/ips-3-5-inch-full-viewing-640x480-tft-display-capacitive-touch-screen
Selects 256Mb or 512Mb
https://docs.espressif.com/projects/esp-at/en/latest/esp32c6/Get_Started/Downloading_guide.html
Input Board

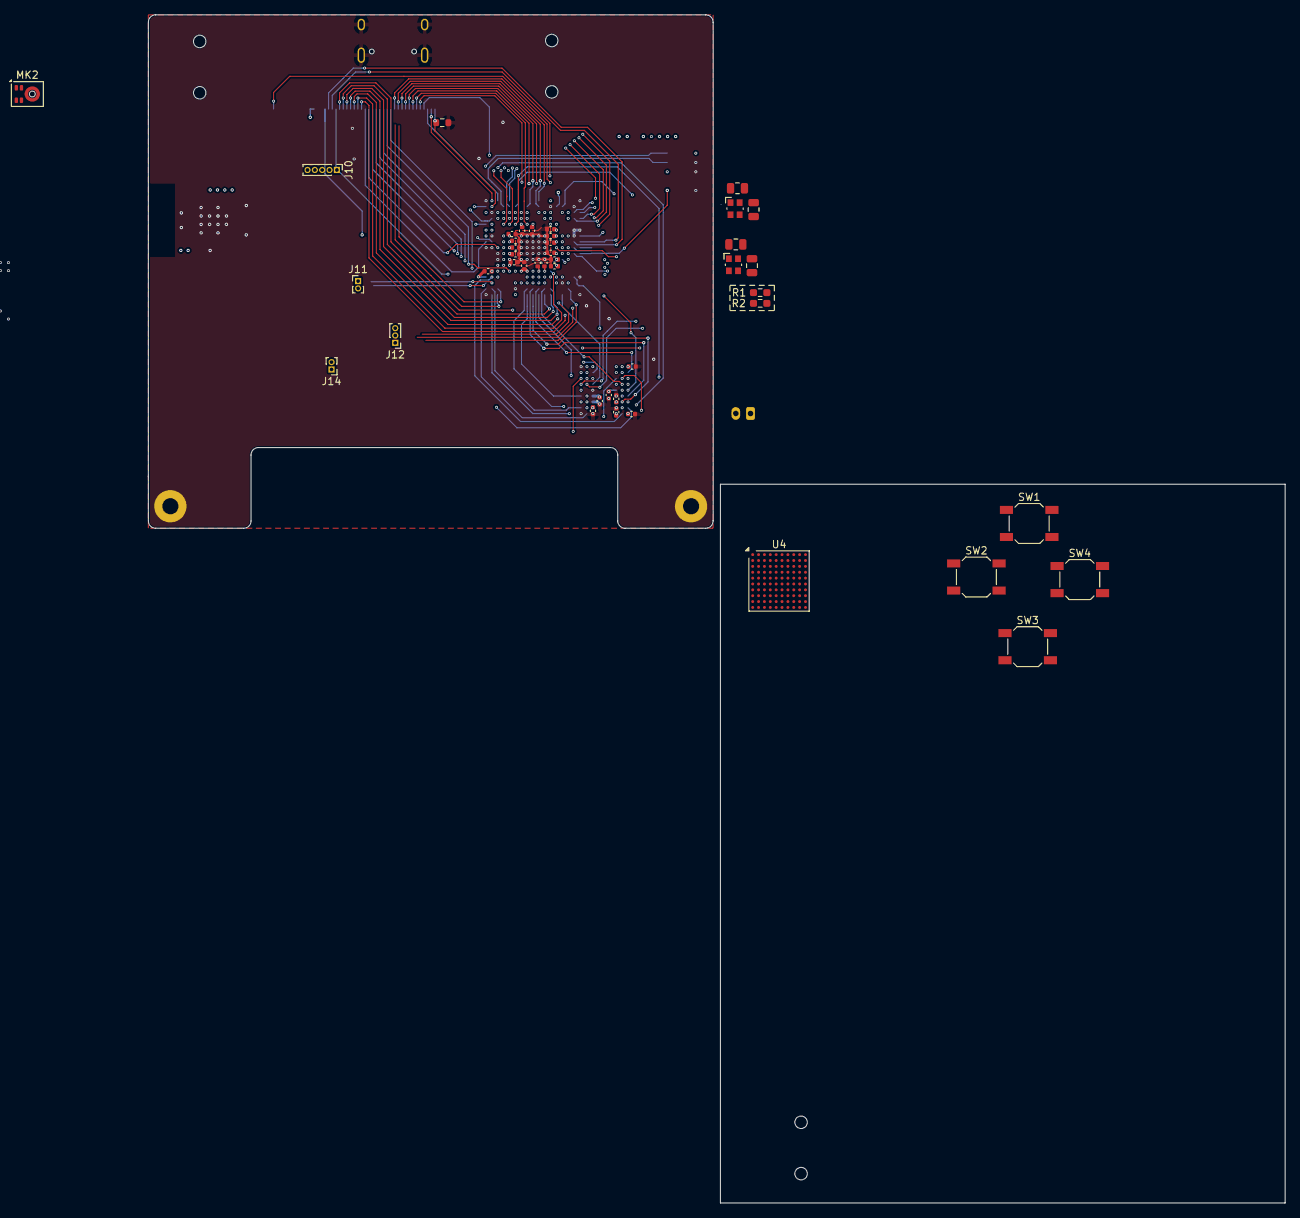
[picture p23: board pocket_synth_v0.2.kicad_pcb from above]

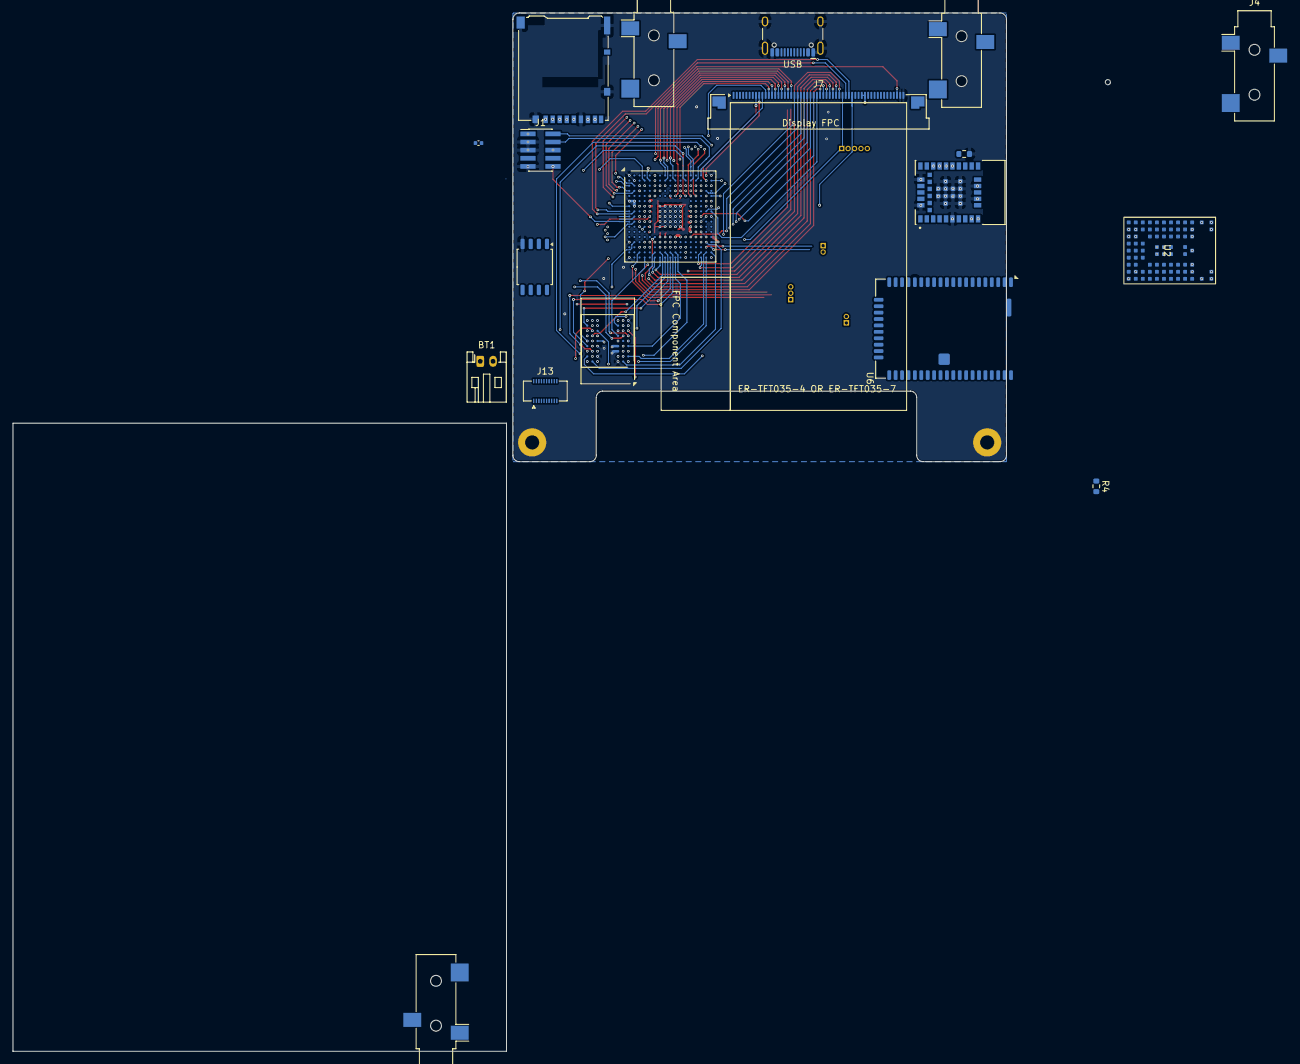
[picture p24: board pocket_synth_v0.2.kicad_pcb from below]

Board: 6 copper layers, 155.0 x 162.0 mm, 64 parts (19 on the bottom side), 120 nets.

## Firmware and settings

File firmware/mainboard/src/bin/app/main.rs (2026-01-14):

#![no_std]
#![no_main]

#[cfg(feature = "alloc")]
extern crate alloc;

mod engine;
mod interface;
mod program;

use defmt::*;

use cortex_m_rt::{ExceptionFrame, exception};

use embassy_executor::Spawner;

use embassy_stm32::rcc::{self};

use embassy_time::Timer;

use {
    // defmt_rtt as _,
    panic_probe as _,
};

use firmware::{
    hardware::{self, preamble::*},
    split_resources,
};

// NOTE: We try to rely on heap allocations as little
// as possible for core elements of the system.
//
// Where possible, core systems should use heapless static
// allocation or allocation pools so their size is known
// and we avoid running into OOM problems.
#[cfg(feature = "alloc")]
use embedded_alloc::LlffHeap as Heap;
#[cfg(feature = "alloc")]
#[global_allocator]
static HEAP: Heap = Heap::empty();

// TODO: add general exception handlers with keypad access to bink error LEDs.
#[embassy_executor::main]
async fn main(spawner: Spawner) {
    info!("program start!");
    // If it returns, something went wrong.
    if let Err(err) = inner_main(spawner).await {
        defmt::panic!("{}", err);
    }
}

// Inner-main allows us us to returns errors via Result instead of relying on panics.
#[expect(
    clippy::future_not_send,
    reason = "Safe in single-threaded, bare-metal embedded context"
)]
#[expect(clippy::items_after_statements, reason = "Keeps related code together")]
async fn inner_main(spawner: Spawner) -> Result<(), ()> {
    // Initialize the ARM Cortex core and STM32 RCC.
    info!("initializing clocks and PLL to 480Mhz");
    let p = hardware::init_peripherals();

    // Segment the peripherals into organized
    // blocks based on their hardware components.
    info!("getting handles to hardware peripherals");
    let r = split_resources!(p);

    // Initialize the hardware components using the segmented resources.
    let hw = hardware::init_hardware(r, spawner).await?;

    // Debug logging of the current clock configuration.
    let clocks = rcc::clocks(&p.RCC);
    println!("System clock speed: {}", clocks.sys);
    println!("APB1  clock speed: {}", clocks.pclk1);
    println!("APB1 Timer clock speed: {}", clocks.pclk1_tim);
    println!("APB2  clock speed: {}", clocks.pclk2);
    println!("APB2 Timer clock speed: {}", clocks.pclk2_tim);

    // After initializing the external SDRAM, we can allocate the heap on it.
    let _sdram: &'static mut [u32] = {
        info!("initializing heap on SDRAM...");

        const HEAP_SIZE: usize = 1024 * 1024 * 16; // 16MB

        info!(
            "sdram_addr={:X} sdram_size={}b heap_size={}b usize::MAX={}",
            hw.sdram.as_ptr() as usize,
            hw.sdram.len(),
            HEAP_SIZE,
            usize::MAX
        );

        if hw.sdram.as_ptr() as usize != 0xC000_0000usize {
            defmt::panic!("invalid SDRAM memory pointer address");
        }

        // Allocate the heap pointer on the memory-mapped external SDRAM.
        unsafe { HEAP.init(hw.sdram.as_ptr() as usize, HEAP_SIZE) };

        unsafe {
            let remaining_sdram = hw.sdram.len() - HEAP_SIZE;

            info!(
                "Adjusting SDRAM available memory based on heap. original_sdram_addr={:X} original_sdram_size={}b heap_size={}b new_sdram_size={}b new_sdram_addr={:X}",
                hw.sdram.as_ptr() as usize,
                hw.sdram.len(),
                HEAP_SIZE,
                remaining_sdram,
                hw.sdram.as_mut_ptr().add(HEAP_SIZE) as usize,
            );

            // "Resize" the array pointer we have to the SDRAM to avoid the allocated heap block.
            core::slice::from_raw_parts_mut(
                hw.sdram.as_mut_ptr().add(HEAP_SIZE),
                remaining_sdram / core::mem::size_of::<u32>(),
            )
        }
    };

    // Start the engine.
    //
    // These are the primary tasks that manage hardware
    // components such as the audio, SD card, USB, etc.
    //
    // Engine start-up is pretty fast as it's fairly quick
    // initialization of the periperals, and spawning a few
    // tasks for managing them.
    info!("starting engine...");
    let engine = engine::start_engine(
        spawner,
        hw.sd_card,
        hw.internal_storage,
        hw.audio,
        hw.audio_codec,
        hw.sai_resources,
        hw.usb_driver,
    )
    .await
    .expect("engine to start");

    info!("starting interface...");
    // todo

    // Starts the actual "program" for the device.
    //
    // This works with the engine and interface tasks to
    // manage the main interface for the device, while
    // running the audio and hardware management tasks.
    info!("starting program...");
    program::start(spawner, engine)
        .await
        .expect("program to start");

    Ok(())
}

/// Custom HardFault handler to improve debugging.
///
/// ref: https://doc.rust-lang.org/beta/embedded-book/start/exceptions.html#the-hard-fault-handler
#[exception]
unsafe fn HardFault(ef: &ExceptionFrame) -> ! {
    // Check `SCB -> CFSR_UFSR_BFSR_MMFSR` register
    // to see the fault and then reference:
    //  https://community.st.com/t5/stm32-mcus/how-to-debug-a-hardfault-on-an-arm-cortex-m-stm32/ta-p/672235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

    error!("HARD FAULT:");
    error!("r0  = 0x{:X}", ef.r0());
    error!("r1  = 0x{:X}", ef.r1());
    error!("r2  = 0x{:X}", ef.r2());
    error!("r3  = 0x{:X}", ef.r3());
    error!("r12 = 0x{:X}", ef.r12());
    error!("lr  = 0x{:X}", ef.lr());

    if (ef.lr() & 0x8) == 1 {
        error!("LR indicates Main Stack Pointer (MSP) TODO double check this is correct")
    } else {
        error!("LR indicates Process Stack Pointer (PSP) TODO double check this is correct")
    }

    // cargo objdump -- -d --no-show-raw-insn --print-imm-hex | grep <PC_HEX_WITHOUT_0x> -A 10 -B 10
    let pc = ef.pc();
    error!("pc: 0x{:X}", pc);
    error!("  Inspect assembled program with:");
    error!(
        "  $ cargo objdump -- -d --no-show-raw-insn --print-imm-hex | grep {:x} -A 10 -B 10",
        pc
    );
    error!("xpsr: {:b}", ef.xpsr());

    // Attempt to read the cortex registers to get more info.
    unsafe {
        let mut core_peri: cortex_m::Peripherals = cortex_m::Peripherals::steal();
        let scb = &mut core_peri.SCB;
        error!("hfsr: {:b}", scb.hfsr.read());

        // Chek HFSR bit 30 to see if we need to check other registers for details.
        if (scb.hfsr.read() & (1 << 30)) != 0 {
            error!("Forced Hard Fault!");
            error!(" HFSR FORCED bit set, see CFSR for details.");

            // NOTE: CFSR contains the UFSR, BFSR, and MMFSR registers.
            error!("  SCB->CFSR: {:b}", scb.cfsr.read());

            // Mask out the UFSR section of the CFSR register (first half).
            if (scb.cfsr.read() & 0xFFFF0000) != 0 {
                let ufsr: u16 = (scb.cfsr.read() >> 16) as u16;
                error!("  Usage Fault Indicator set!");
                error!("    SCB->CFSR->UFSR={:b}", ufsr);

                // TODO: error messages https://developer.arm.com/documentation/dui0552/a/cortex-m3-peripherals/system-control-block/configurable-fault-status-register
            }

            // BFSR
            if (scb.cfsr.read() & 0xFF00) != 0 {
                error!("  Bus Fault Indicator set!");

                let bsfr = (scb.cfsr.read() & 0xFF00) >> 8;
                error!("    SCB->CSFR->BSFR={:b}", bsfr);

                if (bsfr & 0b1) != 0 {
                    // 0
                    error!("    IBUSERR: Instruction bus error.")
                } else if (bsfr & 0b10) != 0 {
                    // 1
                    error!("    PRECISERR: Precise data bus error.");
                    error!("      Offending address (BFAR): 0x{:x}", scb.bfar.read());
                } else if (bsfr & 0b100) != 0 {
                    // 2
                    error!("    IMPRECISERR: Imprecise data bus error.");
                    error!("      Due to an Imprecise data bus error, the return address in the ");
                    error!("       stack does not point to the instruction that caused the fault!");
                } else if (bsfr & 0b1000) != 0 {
                    // 3
                    error!("    UNSTKERR: BusFault on unstacking for a return from exception.");
                } else if (bsfr & 0b10000) != 0 {
                    // 4
                    error!("    STKERR: BusFault on stacking for exception entry.");
                } else {
                    error!("    Unknown bus fault! See register for details.");
                }
            }

            // MMFSR
            if (scb.cfsr.read() & 0xFF) != 0 {
                error!("  Memory Management Indicator set!");
                error!("    Memory fault location: 0x{:X}", scb.mmfar.read());
                // TODO: error messages https://developer.arm.com/documentation/dui0552/a/cortex-m3-peripherals/system-control-block/configurable-fault-status-register
            }
        }
    }

    // TODO: attempt hard fault recovery https://github.com/kendiser5 000/Hardfault-Recovery-Cortex-M4/blob/master/hardfault_handler.c

    loop {}
}

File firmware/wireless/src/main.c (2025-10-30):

#include <zephyr/kernel.h>
#include <zephyr/device.h>

#include <zephyr/logging/log.h>
LOG_MODULE_REGISTER(pocketsynth, LOG_LEVEL_INF);

#include <uart_async_adapter.h>


#define UART_BUF_SIZE 128 // CONFIG_BT_NUS_UART_BUFFER_SIZE
#define UART_WAIT_FOR_BUF_DELAY K_MSEC(50)
#define UART_WAIT_FOR_RX 25 // CONFIG_BT_NUS_UART_RX_WAIT_TIME

// '__device_dts_ord_DT_CHOSEN_uart0_ORD' undeclared here (not in a function)
static const struct device *uart = DEVICE_DT_GET(DT_CHOSEN(synth_uart));
static struct k_work_delayable uart_work;

struct uart_data_t {
	void *fifo_reserved;
	uint8_t data[UART_BUF_SIZE];
	uint16_t len;
};

static K_FIFO_DEFINE(fifo_uart_tx_data);
static K_FIFO_DEFINE(fifo_uart_rx_data);

#ifdef CONFIG_UART_ASYNC_ADAPTER
UART_ASYNC_ADAPTER_INST_DEFINE(async_adapter);
#else
#define async_adapter NULL
#endif

static void uart_cb(const struct device *dev, struct uart_event *evt, void *user_data)
{
	ARG_UNUSED(dev);

	static size_t aborted_len;
	struct uart_data_t *buf;
	static uint8_t *aborted_buf;
	static bool disable_req;

	switch (evt->type) {
	case UART_TX_DONE:
		LOG_DBG("UART_TX_DONE");
		if ((evt->data.tx.len == 0) ||
		    (!evt->data.tx.buf)) {
			return;
		}

		if (aborted_buf) {
			buf = CONTAINER_OF(aborted_buf, struct uart_data_t,
					   data[0]);
			aborted_buf = NULL;
			aborted_len = 0;
		} else {
			buf = CONTAINER_OF(evt->data.tx.buf, struct uart_data_t,
					   data[0]);
		}

		k_free(buf);

		buf = k_fifo_get(&fifo_uart_tx_data, K_NO_WAIT);
		if (!buf) {
			return;
		}

		if (uart_tx(uart, buf->data, buf->len, SYS_FOREVER_MS)) {
			LOG_WRN("Failed to send data over UART");
		}

		break;

	case UART_RX_RDY:
		LOG_DBG("UART_RX_RDY");
		buf = CONTAINER_OF(evt->data.rx.buf, struct uart_data_t, data[0]);
		buf->len += evt->data.rx.len;

		if (disable_req) {
			return;
		}

		if ((evt->data.rx.buf[buf->len - 1] == '\n') ||
		    (evt->data.rx.buf[buf->len - 1] == '\r')) {
			disable_req = true;
			uart_rx_disable(uart);
		}

		break;

	case UART_RX_DISABLED:
		LOG_DBG("UART_RX_DISABLED");
		disable_req = false;

		buf = k_malloc(sizeof(*buf));
		if (buf) {
			buf->len = 0;
		} else {
			LOG_WRN("Not able to allocate UART receive buffer");
			k_work_reschedule(&uart_work, UART_WAIT_FOR_BUF_DELAY);
			return;
		}

		uart_rx_enable(uart, buf->data, sizeof(buf->data),
			       UART_WAIT_FOR_RX);

		break;

	case UART_RX_BUF_REQUEST:
		LOG_DBG("UART_RX_BUF_REQUEST");
		buf = k_malloc(sizeof(*buf));
		if (buf) {
			buf->len = 0;
			uart_rx_buf_rsp(uart, buf->data, sizeof(buf->data));
		} else {
			LOG_WRN("Not able to allocate UART receive buffer");
		}

		break;

	case UART_RX_BUF_RELEASED:
		LOG_DBG("UART_RX_BUF_RELEASED");
		buf = CONTAINER_OF(evt->data.rx_buf.buf, struct uart_data_t,
				   data[0]);

		if (buf->len > 0) {
			k_fifo_put(&fifo_uart_rx_data, buf);
		} else {
			k_free(buf);
		}

		break;

	case UART_TX_ABORTED:
		LOG_DBG("UART_TX_ABORTED");
		if (!aborted_buf) {
			aborted_buf = (uint8_t *)evt->data.tx.buf;
		}

		aborted_len += evt->data.tx.len;
		buf = CONTAINER_OF((void *)aborted_buf, struct uart_data_t,
				   data);

		uart_tx(uart, &buf->data[aborted_len],
			buf->len - aborted_len, SYS_FOREVER_MS);

		break;

	default:
		break;
	}
}

// Allocate the UART buffer and enable the receiver.
static void uart_work_handler(struct k_work *item)
{
	struct uart_data_t *buf;

	buf = k_malloc(sizeof(*buf));
	if (buf) {
		buf->len = 0;
	} else {
		LOG_WRN("Not able to allocate UART receive buffer");
		k_work_reschedule(&uart_work, UART_WAIT_FOR_BUF_DELAY);
		return;
	}

	uart_rx_enable(uart, buf->data, sizeof(buf->data), UART_WAIT_FOR_RX);
}

static bool uart_test_async_api(const struct device *dev)
{
	const struct uart_driver_api *api =
			(const struct uart_driver_api *)dev->api;

	return (api->callback_set != NULL);
}

// Initialize the UART peripheral.
static int uart_init(void)
{
	int err;
	int pos;
	struct uart_data_t *rx;
	struct uart_data_t *tx;

	if (!device_is_ready(uart)) {
		return -ENODEV;
	}

	rx = k_malloc(sizeof(*rx));
	if (rx) {
		rx->len = 0;
	} else {
		return -ENOMEM;
	}

	k_work_init_delayable(&uart_work, uart_work_handler);


	if (IS_ENABLED(CONFIG_UART_ASYNC_ADAPTER) && !uart_test_async_api(uart)) {
		/* Implement API adapter */
		uart_async_adapter_init(async_adapter, uart);
		uart = async_adapter;
	}

	err = uart_callback_set(uart, uart_cb, NULL);
	if (err) {
		k_free(rx);
		LOG_ERR("Cannot initialize UART callback");
		return err;
	}

	// if (IS_ENABLED(CONFIG_UART_LINE_CTRL)) {
	// 	LOG_INF("Wait for DTR");
	// 	while (true) {
	// 		uint32_t dtr = 0;

	// 		uart_line_ctrl_get(uart, UART_LINE_CTRL_DTR, &dtr);
	// 		if (dtr) {
	// 			break;
	// 		}
	// 		/* Give CPU resources to low priority threads. */
	// 		k_sleep(K_MSEC(100));
	// 	}
	// 	LOG_INF("DTR set");
	// 	err = uart_line_ctrl_set(uart, UART_LINE_CTRL_DCD, 1);
	// 	if (err) {
	// 		LOG_WRN("Failed to set DCD, ret code %d", err);
	// 	}
	// 	err = uart_line_ctrl_set(uart, UART_LINE_CTRL_DSR, 1);
	// 	if (err) {
	// 		LOG_WRN("Failed to set DSR, ret code %d", err);
	// 	}
	// }

	tx = k_malloc(sizeof(*tx));

	if (tx) {
		pos = snprintf(tx->data, sizeof(tx->data),
			       "Starting Nordic UART service sample\r\n");

		if ((pos < 0) || (pos >= sizeof(tx->data))) {
			k_free(rx);
			k_free(tx);
			LOG_ERR("snprintf returned %d", pos);
			return -ENOMEM;
		}

		tx->len = pos;
	} else {
		k_free(rx);
		return -ENOMEM;
	}

	err = uart_tx(uart, tx->data, tx->len, SYS_FOREVER_MS);
	if (err) {
		k_free(rx);
		k_free(tx);
		LOG_ERR("Cannot display welcome message (err: %d)", err);
		return err;
	}

	err = uart_rx_enable(uart, rx->data, sizeof(rx->data), UART_WAIT_FOR_RX);
	if (err) {
		LOG_ERR("Cannot enable uart reception (err: %d)", err);
		/* Free the rx buffer only because the tx buffer will be handled in the callback */
		k_free(rx);
	}

	return err;
}

void error(void)
{
	// dk_set_leds_state(DK_ALL_LEDS_MSK, DK_NO_LEDS_MSK);

	while (true) {
		/* Spin for ever */
		k_sleep(K_MSEC(1000));
	}
}

int main(void)
{
        int err = 0;

        LOG_INF("Initializing UART...");

        err = uart_init();
		if (err) {
			LOG_ERR("Failed to initialize UART");
			error();
		}

        LOG_INF("UART initialized!");


        return err;
}

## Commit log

2025-09-06 feat: import board and library from previous revision, start board modifications
    [5034800540.stp, 541325097.stp, 687106182122+(rev1).stp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]
2025-09-07 feat: various component and layout changes
    [MCU.kicad_sch, Same_Sky_CMS-160925-078SP.step, audio.kicad_sch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]
2025-09-07 feat: add menu buttons and speaker connectors
    [532610271.STEP, B3S_100[].step, DA7280-00FVC.stp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]
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2025-09-08 feat: add bulk of SDRAM routing
    [memory.kicad_sch]
2025-09-08 feat: start MIDI and CV schematic
    [5pin SO6.step, MCU.kicad_sch, audio.kicad_sch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]
2025-09-09 feat: various schematic organization
    [MCU.kicad_sch, audio.kicad_sch, midi_cv.kicad_sch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]
2025-09-09 feat: schematic organization, MIDI port routing
    [DAEX-9-4SM.step, MCU.kicad_sch, audio.kicad_sch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]
2025-09-09 feat: route audio components
    [MCU.kicad_sch, audio.kicad_sch, display.kicad_sch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]
2025-09-09 feat: start adding FM receiver
    [MCU.kicad_sch, SI4704-D60-GMR.stp, memory.kicad_sch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]
2025-09-09 feat: add codec 3D model
    [NAU88C22YG.STEP]
2025-09-10 feat: FM receiver routing
    [MCU.kicad_sch, audio.kicad_sch, memory.kicad_sch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]
2025-09-11 feat: FM transmitter and routing
    [audio.kicad_sch]
2025-09-11 feat: route dedicated audio I2C bus
    [MCU.kicad_sch, audio.kicad_sch, memory.kicad_sch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]
2025-09-11 fix: I2C routing for keypad
    [keypad.kicad_sch, midi_cv.kicad_sch]
2025-09-11 fix: set different I2C addresses for FM ICs
    [audio.kicad_sch]
2025-09-11 fix: DRC drill clearance errors
    [memory.kicad_sch, pocket_synth.kicad_sch]
2025-09-11 feat: power system routing
    [power.kicad_sch]
2025-09-11 feat: SD card SPI bus and routing
    [MCU.kicad_sch]
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2025-09-12 feat: start adding Wifi module
    [ESP32-S3-MINI-1U-N8.STEP, rf.kicad_sch]
2025-09-12 feat: various routing and organization
    [MCU.kicad_sch, audio.kicad_sch, memory.kicad_sch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]
2025-09-12 feat: schematic organization and ERC cleanup
    [MCU.kicad_sch, display.kicad_sch, keypad.kicad_sch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]
2025-09-12 feat: add missing power button controller
    [pocket_synth.kicad_sch, power.kicad_sch]
2025-09-13 feat: add test points and top and bottom ground pours
    [audio.kicad_sch, memory.kicad_sch, midi_cv.kicad_sch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]
2025-09-13 feat: add more test points
    [audio.kicad_sch, memory.kicad_sch, power.kicad_sch]
2025-09-13 feat: add touch screen connector, input I2C bus
    [MCU.kicad_sch, audio.kicad_sch, display.kicad_sch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]
2025-09-13 feat: remove bitmagic connector
    [MCU.kicad_sch]
2025-09-13 feat: add IO expander for velocity pads
    [ADS7128IRTER.stp, MCU.kicad_sch, keypad.kicad_sch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]
2025-09-13 chpre: remove extraneous ground vias
    [rf.kicad_sch]
2025-09-13 feat: various ERC and DRC cleanup
    [MCU.kicad_sch, audio.kicad_sch, display.kicad_sch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]
2025-09-13 fix: incorrect symbol defined for MCU
    [MCU.kicad_sch]
2025-09-13 fix: more ERC cleanup
    [audio.kicad_sch, display.kicad_sch, midi_cv.kicad_sch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]
2025-09-14 feat: remove analog MIDI thru
    [MCU.kicad_sch, midi_cv.kicad_sch, pocket_synth.kicad_sch]
2025-09-14 feat: more routing and DRC cleanup
    [MCU.kicad_sch, keypad.kicad_sch, lighting.kicad_sch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]
2025-09-14 feat: more DRC cleanup
    [MCU.kicad_sch, audio.kicad_sch, keypad.kicad_sch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]
2025-09-14 feat: finally add power button!
    [436331045822.stp, memory.kicad_sch, power.kicad_sch]
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2025-09-14 feat: switch FM transmitter to I2S
    [825-22-002-10-001101.stp, audio.kicad_sch, memory.kicad_sch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]
2025-09-14 feat: add FM reset pins, add fiducials
    [MCU.kicad_sch, audio.kicad_sch, peripherals.kicad_sch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]
2025-09-14 feat: add display reset connection
    [MCU.kicad_sch, display.kicad_sch, pocket_synth.kicad_sch]
2025-09-14 feat: change FM receiver to newer model with RDS
    [MCU.kicad_sch, audio.kicad_sch, memory.kicad_sch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]
2025-09-14 chore: make ERC happy
    [peripherals.kicad_sch, pocket_synth.kicad_sch, power.kicad_sch]
2025-09-15 feat: route thermalcouple, add top side fiducials
    [pocket_synth.kicad_sch]
2025-09-15 feat: add USB-PD source mode boost converter, mosets, and PD controller
    [memory.kicad_sch, power.kicad_sch]
2025-09-16 feat: add USB-PD power distribution switches
    [power.kicad_sch]
2025-09-17 feat: route USB-PD power distribution switches and boost converter
    [memory.kicad_sch, power.kicad_sch]
2025-09-18 chore: update power notes
    [power.kicad_sch]
2025-09-18 feat: clean up routing, remove metronome light
    [MCU.kicad_sch, lighting.kicad_sch, memory.kicad_sch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]
2025-09-19 feat: routing cleanup and start of BOM selection
    [MCU.kicad_sch, audio.kicad_sch, display.kicad_sch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]
2025-09-20 feat: update various components to 0402
    [MCU.kicad_sch, audio.kicad_sch, display.kicad_sch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]
2025-09-20 feat: various DFM cleanup steps
    [audio.kicad_sch, keypad.kicad_sch, power.kicad_sch]
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2025-09-21 feat: various routing cleanup, add SD flash
    [MCU.kicad_sch, audio.kicad_sch, display.kicad_sch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]
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2025-09-22 feat: set correct footprint for matrix diodes
    [keypad.kicad_sch]
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2025-09-23 feat: swap out of stock components
    [MCU.kicad_sch, audio.kicad_sch, display.kicad_sch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]
2025-09-24 feat: various cleanup and BOM adjustment, split audio in into two switches
    [MCU.kicad_sch, audio.kicad_sch, display.kicad_sch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]
2025-09-24 feat: fix RGB LED circuit
    [MCU.kicad_sch, lighting.kicad_sch]
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2025-09-29 feat: change charger, fuel gauge, and battery connector, re-route power system
    [2082940020.stp, BQ27531YZFR-G1.step, MCU.kicad_sch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]
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2025-10-07 feat: add pins in silkscreen, various DFM adjustments for JLC
    [MCU.kicad_sch, audio.kicad_sch, display.kicad_sch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]
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2025-10-07 fix: rotation offsets and LEDs on wrong side of board
    [MCU.kicad_sch, audio.kicad_sch, keypad.kicad_sch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]
2025-10-07 fix: accidentally excluding switches from board
    [keypad.kicad_sch]
2025-10-08 chore: remove BOM excluded components from positions file
    [peripherals.kicad_sch]
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2025-10-09 chore: add missing datasheet for FM receiver
    [audio.kicad_sch]
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2025-10-22 chore: document errata for v0.1 boards
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2025-10-24 feat: fix b1s7531-g1 command codes
    [mod.rs]
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2025-10-26 feat: fix PLL config, integrate keypad LEDs
    [app.rs, mod.rs]
2025-10-26 feat: start fixing internal SD storage library in fork
    [app.rs, mod.rs]
2025-10-27 feat: fix keypad LED interface to use task
    [app.rs, mod.rs]
2025-10-27 feat: fix SDRAM parameters and enable
    [app.rs, mod.rs]
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2025-11-10 fix incorrect keypad light colors
    [mod.rs]
2025-11-10 fix boot sequence not catching input events
    [app.rs, mod.rs]
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2025-11-30 add board schematic and errata links to README.md
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2025-12-29 fix SAI config for i2s protocol
    [audio.rs]
2025-12-29 fixed audio via `iobufen` flag being cleared by `nau88c22` library erroneously
    [audio.rs]
2025-12-29 fix sample format conversion
    [audio.rs]
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2025-12-29 correct audio component usage in main program
    [app.rs, mod.rs]
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2025-12-31 fixed SAI buffer overrun with `opt-level` > 0
    [audio.rs, internal_storage.rs]
2026-01-01 fix zero gain on DAC output
    [codec.rs, mod.rs]
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2026-01-08 add drive error type and simplify task
    [mod.rs]
2026-01-14 fix heap using stack address pointer
    [main.rs, mod.rs]
2026-01-15 resolved system audio playback routine buzzing
    [mod.rs]
2026-01-16 fix sending unsigned audio data to signed i2s peripheral causing audio quality issues
    [mod.rs]
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2026-01-27 add NINA-W13 Wifi module and BM83 Bluetooth Audio
    [pocket_synth_v0.2.kicad_pcb, pocket_synth_v0.2.kicad_sch]
